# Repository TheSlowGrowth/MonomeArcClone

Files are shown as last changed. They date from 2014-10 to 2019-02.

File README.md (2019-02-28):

# Monome Arc Clone

An open source, protocol-compatible clone of the monome arc.

## Before you start

Please note: if you encounter a problem, please **do not post on the
monome forums**! Tehn will surely help you, but I don’t want my clone
to cause them trouble and work. I’m very happy that they make their
protocols open and I would like them to continue to do so in the spirit
of openness.

For assistance, please write an email to my address instead:
<mail@johannesneumann.net> I will try to help you out.

## Required tools

During assembly and setup you will need the following tools

-   AVR ISP programming device (supported by avrdude). I recommend
    [USBasp](http://www.fischl.de/usbasp/) or any of its clones.
    Alternatively you can also use STK500v2 clones or any other
    programmer that supports the ISP protocol. You get something like
    this on ebay for under 20€.
-   Soldering iron, decent(!) flux, tweezers, solder wick
-   a computer capable of flashing AVRs and FTDI EEPROMs
-   a multimeter

## Software installation

Before you start, please install all the software that’s needed to run monome devices. Please look at the instructions provided by [http://monome.org](http://monome.org/). Even though you might not have a functioning monome at this point, we will need the drivers during the setup process.

Install the drivers for your AVR ISP programmer, if you haven’t already.

### Windows

Install *WINAVR* from [this link](http://www.webring.org/l/rd?ring=avr;id=59;url=http://winavr.sourceforge.net/). This will install a AVR compiler and (more important) a tool called *avrdude* to upload the software to the ATMega88p microprocessor used in the device.

Install *AVR-Burn-O-Mat* from [this link](http://avr8-burn-o-mat.aaabbb.de/). This little tool will make it easier to upload the software to the chip as it provides a nice graphical user interface to *avrdude* installed with WINAVR.

Now we need to edit some files. Unfortunately as I am writing this (05.11.2014) it seems that some versions of *avrdude* and *AVR-Burn-O-Mat* don’t know the ATMega88p processor yet. So we teach them that it exists.

First, go to C:\\WINAVR\...\....\\bin\\avrdude.conf and open it with a text editor (I recommend geany).

Search for "ATMega88p". If it takes you to something like this:

```
#------------------------------------------------------------

# Atmega88p

#------------------------------------------------------------
```

…then you don’t have to edit anything and the file is fine. Simply go to the next step.

If nothing is found, search for this part:

```
#------------------------------------------------------------

# ATmega88

#------------------------------------------------------------
```

This is the header for the (almost) equal ATMega88. We simply copy the whole passage below this line (down to the next similar looking header) and change a few things. The whole passage you have to copy is roughly 200 lines long.

Duplicate the whole passage and change the beginning to:

```
#------------------------------------------------------------

# ATmega88p

#------------------------------------------------------------

part

id = "m88p";

desc = "ATMEGA88P";

has_debugwire = yes;

flash_instr = 0xB6, 0x01, 0x11;

eeprom_instr = 0xBD, 0xF2, 0xBD, 0xE1, 0xBB, 0xCF, 0xB4, 0x00,

0xBE, 0x01, 0xB6, 0x01, 0xBC, 0x00, 0xBB, 0xBF,

0x99, 0xF9, 0xBB, 0xAF;

stk500_devcode = 0x73;

# avr910_devcode = 0x;

signature = 0x1e 0x93 0x0f;

pagel = 0xd7;

bs2 = 0xc2;

...

... more stuff follows here ...

...
```

Now avrdude knows the microprocessor.

Now we have to teach *AVR-Burn-O-Mat* as well. Go to the installation directory (mine is: `D:\Program Files (x86)\AVR Burn-O-Mat)` and open the file `AVR8_Burn_O_Mat_Config.xml`. With a text editor (e.g. geany).

Again, search for "Atmega88p". If it can be found, all is well and you don't have to do anything here. If nothing is found, search for "Atmega88". It should take you to this line:

```
<AVR name="m88" caption="ATmega88">
   <Fuse name="UNUSED_E7" bit="7" ...

```
Copy the whole block (everything between `<AVR name="m88" ... ` and `</AVR>`) and change the first line to 
```
<AVR name="m88p" caption="ATmega88p">
```
Now *AVR-Burn-O-Mat* can program your Atmega88p processor.

Now open *AVR-Burn-O-Mat* and go to the settings page. Check if the directories are correct and enter the connection settings for your programmer.

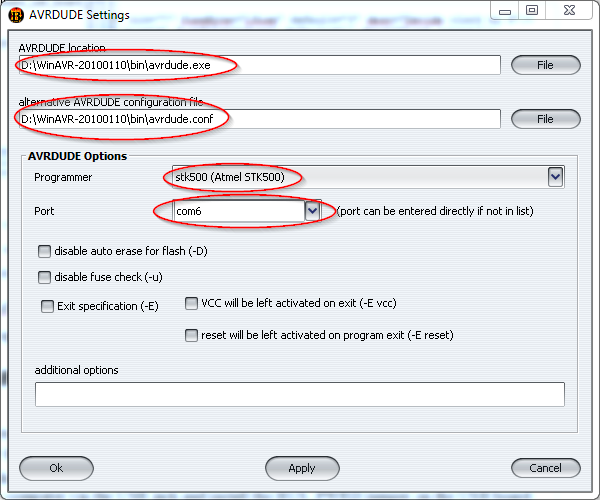
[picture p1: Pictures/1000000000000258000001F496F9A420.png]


I’m using an STK500V2 clone here, but if you click the dropdown menu, it will give you other options, such as USBasp. For most USB programmers, the Port must be set to "usb" or (if they are based on a serial COM interface) the respective COM port. You can open the device manager and plug in your programmer, then it should display the COM port in brackets behind the device name.

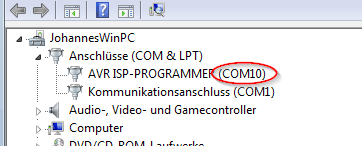
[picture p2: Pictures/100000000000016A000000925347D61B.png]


Install FT-Prog from [this website](http://www.ftdichip.com/Support/Utilities.htm). We will need it to configure the FTDI USB chip on the board.

### Linux

On Linux, install avrdude using your system’s package manager.

Compile libftdi with the confuse library already present, and make sure you can run the ftdi_eeprom command it comes with. This is currently untested on linux, please refer to [this guide](https://waterpigs.co.uk/articles/ftdi-configure-mac-linux/) for pointers on how to do it.

### Mac OS X

Install avrdude, and avr-gcc if you want to compile your own hex files. You can do this either manually, or via [CrossPack](https://obdev.at/products/crosspack/download.html).

In order to be able to flash the FTDI chip’s EEPROM, you’ll need to install libftdi with the confuse library already installed. This is possible either manually, or using homebrew with a change to the libftdi formula detailed [here](https://waterpigs.co.uk/articles/ftdi-configure-mac-linux/).

Some old versions of CrossPack will be missing the avrdude reference files for the ATMega88p. You can test this by running `avrdude -c stk500v2 -p m88p`. If you get `avrdude: AVR Part "88p" not found.` then follow the instructions in the Windows section above, duplicating the ATMega88 definition for the 88p. Look for an avrdude.conf file to make these changes in, e.g. `/usr/local/CrossPack-AVR-20100115/etc/avrdude.conf`

## USB Board Assembly

I won’t give step-by-step instructions for soldering. If you are not familiar with soldering and electronics in general, please do an easier project first. It can become very frustrating otherwise.

Once you’re done assembling the USB board, go to the device manager (Windows) or USB Prober (Mac OS). Connect the USB board to your computer via the USB jack and install the BUS\_PWRD jumper on the USB board. You should see the device manager refresh and a new COM port device will appear.

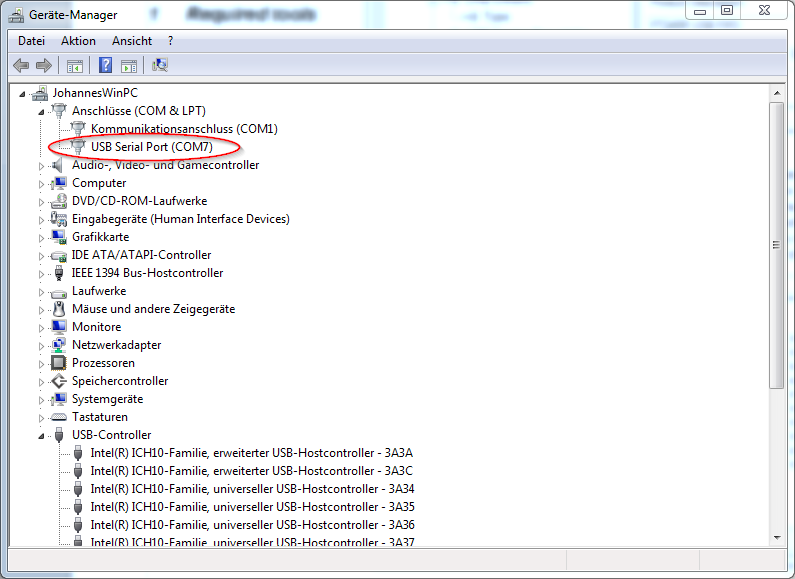
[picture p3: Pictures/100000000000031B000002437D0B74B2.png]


If it does not appear, please disconnect it immediately and check your soldering!

Now we have to check the voltage of the on-board regulator. Connect a multimeter to the pins highlighted in the following picture:

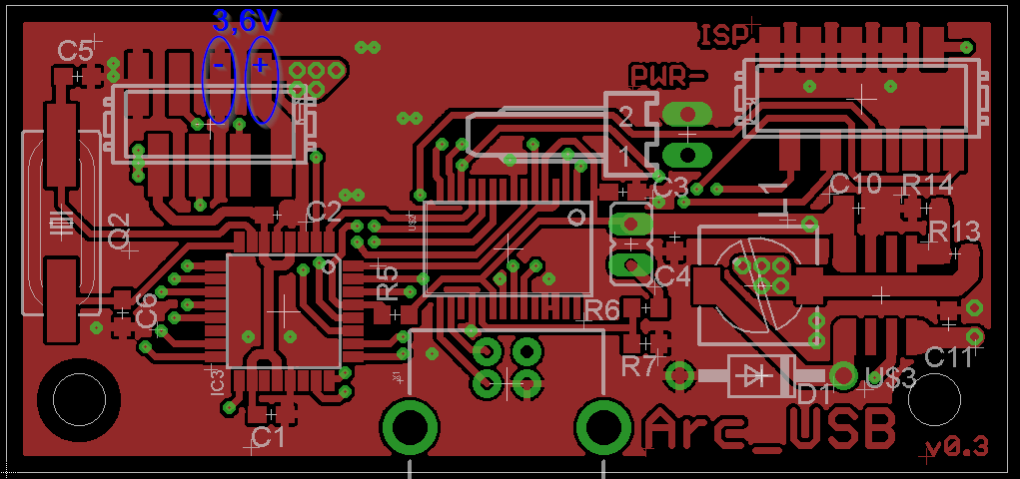
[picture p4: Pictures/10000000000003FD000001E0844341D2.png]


Your meter should read 3,6V (or thereabouts). Fine, it looks like everything is okay.

Lets go on and flash the firmware to the chip. Connect your programmer to the 10-pin connector on the USB board. This connector is not the one commonly used for AVR devices, but it uses the same pinout and attaches to the same type of cables. You can simply use your programmers 10-pin cable and crimp micromatch connector to it. This should now be plugged into the USB board. Check the orientation. A good help can be the four ground-pins, which are connected to each other. On both the USB board and the programmer. Pin 1 of the cable is on the opposite side. In the image above, it is the pin on the bottom right of the connector, next to the "R14" label.

Also be sure, that the USB board is plugged into your computer as well and the BUS\_PWRD jumper is installed, so the processor receives power.

### Windows (AVR-Burn-O-Mat + FT_PROG)

Open *AVR-Burn-O-Mat *and connect your programmer to your PC.

First, we need to change the fuse-bits in the processor, to use the external 20MHz crystal as a clock source. Select Atmega88p from the "AVR type" menu. Then click on "Fuses"

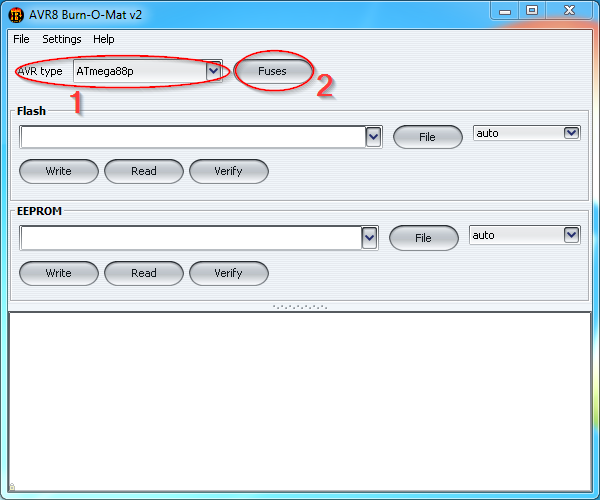
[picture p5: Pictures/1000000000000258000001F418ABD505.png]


In the new window, click "read fuses".

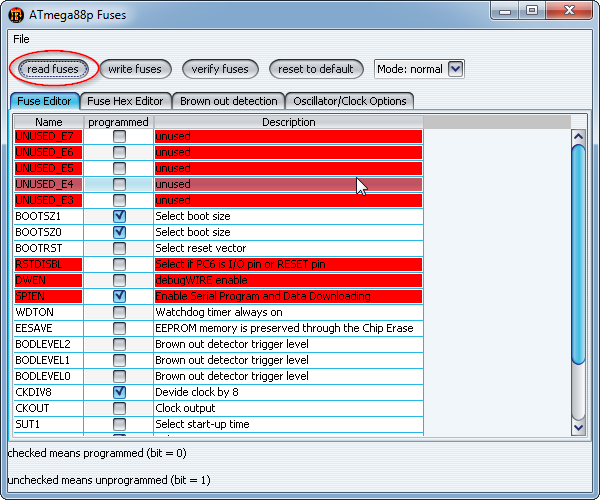
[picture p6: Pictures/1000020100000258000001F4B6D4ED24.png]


You should see some commands run in the bottom of the main window and eventually a message will pop up, saying: "fuses successfully read". If not: Check the commands in the main window. They can give you a hint to where the problem is. Usually the programmer settings are wrong (wrong COM port\...) or the USB board is not connected properly. Some programmers offer a "low speed" programming mode, this should be used, as the processor is currently still running at its internal low clock speed.

If verything is fine, we can edit the fuse-bits to use the external crystal. Click on the "Oscillator/Clock Options" tab, then un-tick "divide system clock by 8" and select the "Full swing crystal oscillator" tab.

Double check everything! You might screw your chip up! Never attempt to write the fuses, if you were not able to correctly read them before. You might end up with a chip that has its programming interface disabled and can’t be rescued even with professional equipment.

Okay, once you are sure, everything is correct and matches the image below, you can click "write fuses" and again, some commands should run in the main window and a message should say: "Fuses successfully written". Then click "read fuses" again. If they can be read successfully, you have done everything right.

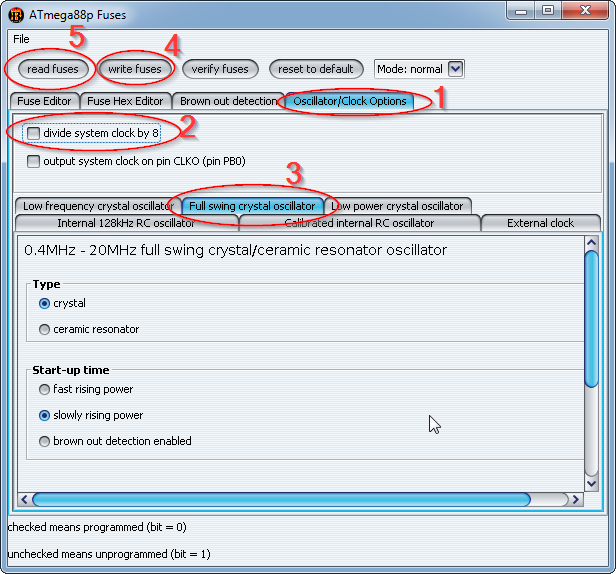
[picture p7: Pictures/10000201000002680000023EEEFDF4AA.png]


Now we can flash the firmware. Close the fuses window and select the firmware file in the main window. I recommend to use the pre-compiled one in the repository. I want to build an arc 4 here, so I chose the matching firmware. Be sure to use the right file. Using another file will probably make the processor "think" its connected to some hardware which is not there. This can create short circuits and might destroy the chip. So please double check here!

Click "write" and the commands in the bottom of the window should start executing again. Eventually it will say "Flash sucessfully written."

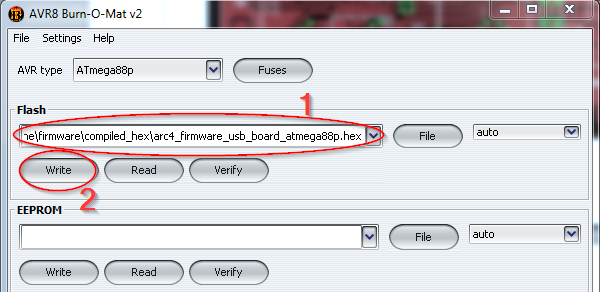
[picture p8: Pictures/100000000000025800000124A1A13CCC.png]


Nice! Now you can unplug the programmer.

Now we have to configure the USB-chip on the board to be recognized by serialosc so you can use your clone just like a real monome arc.

Start FT\_PROG and connect the USB board to your computer via its USB connector. In the FT\_PROG window, click the search icon until it displays your device.

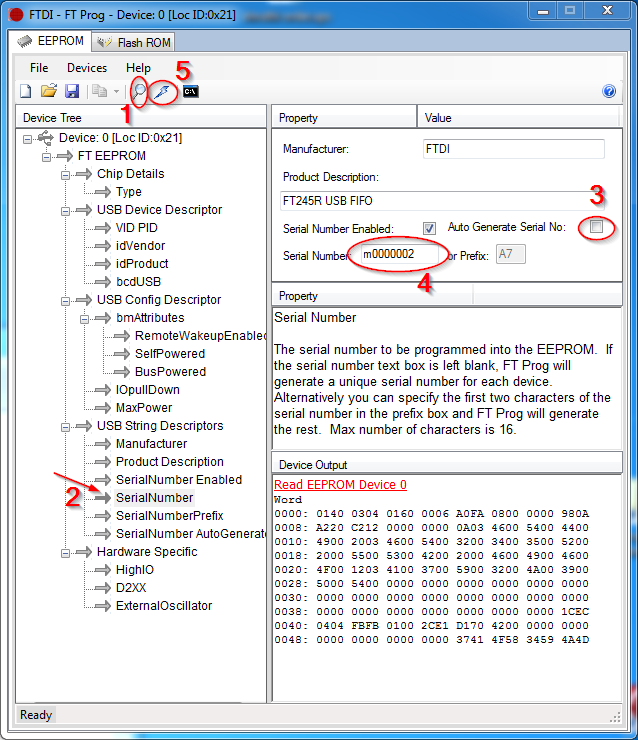
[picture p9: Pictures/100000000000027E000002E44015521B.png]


Eventually after a few retries you get this. Go to the "SerialNumber" tab and untick "Auto Generate Serial No:". Now you can edit the "serial number" field. Enter a serial number like in the image above. It should start with an "m" and the numbers after that are irrelevant, but I found that they should be 7 digits long. They represent the "unique number" of your device. If you have other monomes, be sure that you use a different serial number that the one of your other devices. Also change the manufacturer to "monome", this is important for compatibility with monome eurorack modules and the Aleph. Once you’re done, click the flash symbol and program the new settings to the chip.

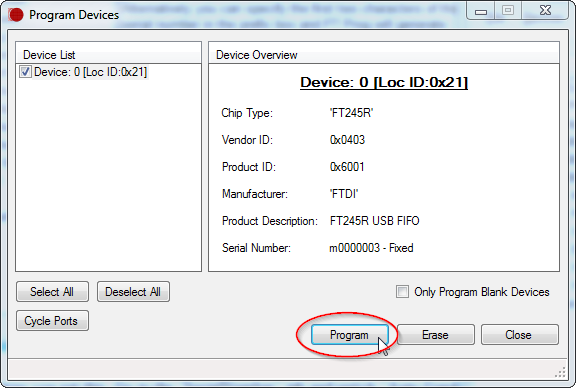
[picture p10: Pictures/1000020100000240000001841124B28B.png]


### Linux/Mac OS (avrdude + libftdi ftdi_eeprom)

Connect your AVR programmer to your computer, and the USB board to the programmer. In each of the following commands, replace `YOUR_PROGRAMMER_ID` with the relevant ID (e.g. stk500v2) and `YOUR_PROGRAMMER_PORT` with the relevant port (e.g. `/dev/cu.usbmodem00177932`.

First, set the fuses, based on [this fuse calculation](http://eleccelerator.com/fusecalc/fusecalc.php?chip=atmega88p&LOW=D6&HIGH=DF&EXTENDED=F9&LOCKBIT=FF):

`avrdude -V -p m88p -c YOUR_PROGRAMMER_ID -P YOUR_PROGRAMMER_PORT -B 10 -e -u -U lfuse:w:0xD6:m -U hfuse:w:0xDF:m -U efuse:w:0xF9:m -U lock:w:0xFF:m`

Then, flash the USB board firmware. Swap `arc4_` for `arc2_` in the unlikely event you’re building a two-ring arc:

`avrdude -V -p m88p -c YOUR_PROGRAMMER_ID -P YOUR_PROGRAMMER_PORT -B 2 -U flash:w:./firmware/compiled_hex/arc4_firmware_usb_board_atmega88p.hex:i -U lock:w:0xFF:m`

To flash the FTDI EEPROM, edit `firmware/monome-arc-clone-ftdi-eeprom.conf` to have your desired serial number (which must be m followed by seven digits), then run the following command with your FTDI driver disabled:

`ftdi_eeprom --flash-eeprom firmware/monome-arc-clone-ftdi-eeprom.conf`

Don’t forget to re-enable your FTDI driver afterwards! Refer to this [libftdi guide](https://waterpigs.co.uk/articles/ftdi-configure-mac-linux/) for more information.

### Testing

Now you can open a monome app with your USB board connected, and you should see your clone appear in the device list. If it does not appear, check your serialosc settings.

## Pot board and ring board assembly

Assemble the ring boards and the pot boards. Start with one pair of them to find errors early.

At full brightness, each LED is supplied with a 3.3V square wave with 25% duty cycle, current limited to around 2.6mA (with a 9.1kohm current set resistor). Not all LEDs perform well at such low currents. Testing found the IN-S63AT5UW to be an excellent trade-off between price and performance. Prices in the comparison are from late 2018.

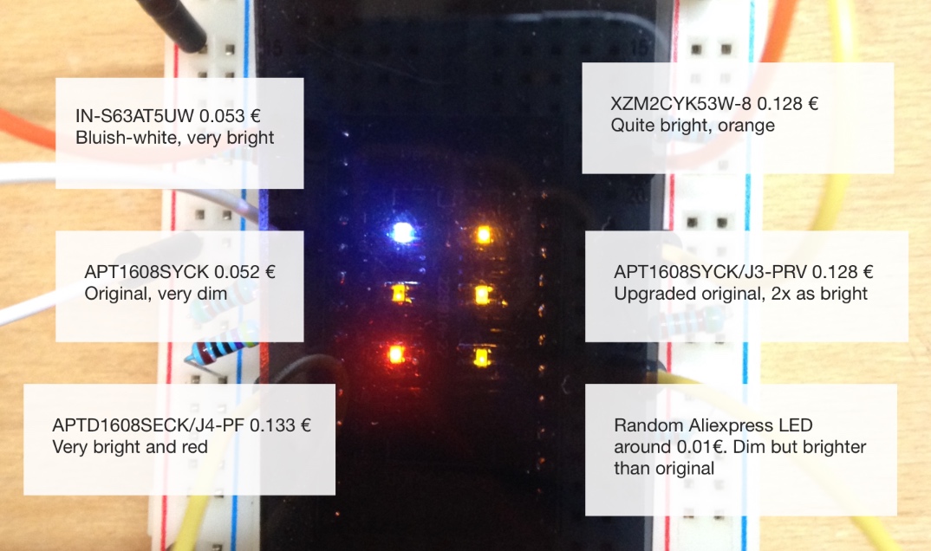
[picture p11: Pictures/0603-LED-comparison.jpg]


When soldering the surface mounted headers which connect each ring board to the encoder board, solder only one connector first, insert the other connector onto that, then temporarily screw the boards together and make a couple of solder joints to fix the other connector in exactly the right mating position. If soldered without checking the location, you risk the boards being misaligned.

Use the 8pin micromatch connectors and ribbon cables to connect the pot board to the USB board via their micromatch connectors (Not the one marked with ISP, the smaller one.) Connect the USB board to your computer and check the BUS\_PWRD jumper. The USB board should now receive power, and supply the pot board via the ribbon cable that connects the two.

Attach your AVR programmer to the board, then set the fuses and flash the firmware as with the USB Board, but using `firmware_pot_board_atmega88p.hex` rather than the USB board hex file.

Once the pot boards processor is programmed with the right fuses and firmware, you should disconnect the usb cable and set the address selection switch to off/off. This equals to address 0, which is used for the first LED ring in the monome arc clone.

Now attach the led ring.

Connect the USB board to the computer again and the led ring should light up for a short time (part of the startup animation). Open the [monome arc test app](http://docs.monome.org/lib/exe/fetch.php?media=app:monome_test_110.zip) and check everything.

Then assemble the other boards and connect them to the ribbon cable. Flash them the same way and check them with the test app. Be sure to use the right addresses:

```
  ------------- ---------- ----------
  Ring number   Switch 2   Switch 1
  0             Off        Off
  1             Off        On
  2             On         Off
  3             On         On
  ------------- ---------- ----------
```

Double check that all the boards function correctly before final assembly. Make sure that all LEDs light, that the encoders send turn and button press messages, and that the boards are in the right order.

If you don’t have Max MSP and don’t want to install the very large free Max player, you can use the small Puredata arc test patch in `firmware/arc-scratchpad.pd` to test and debug your arc. It should run in any version of Puredata, and requires no externals.

## Physical Case Construction and Assembly

Assuming you’re working with a milled panel based on `case/Alu Faceplate.pdf` and laser cut acrylic parts based on the Glas-Ring and Light_Shaper drawings, assembly is quite straightforward. The fit of the laser cut parts is tight, and often the outer diameter is slightly larger on one edge than the other, so look carefully at the edge angles of both parts and experiment with their orientation to find the best results. You can see the angles here:

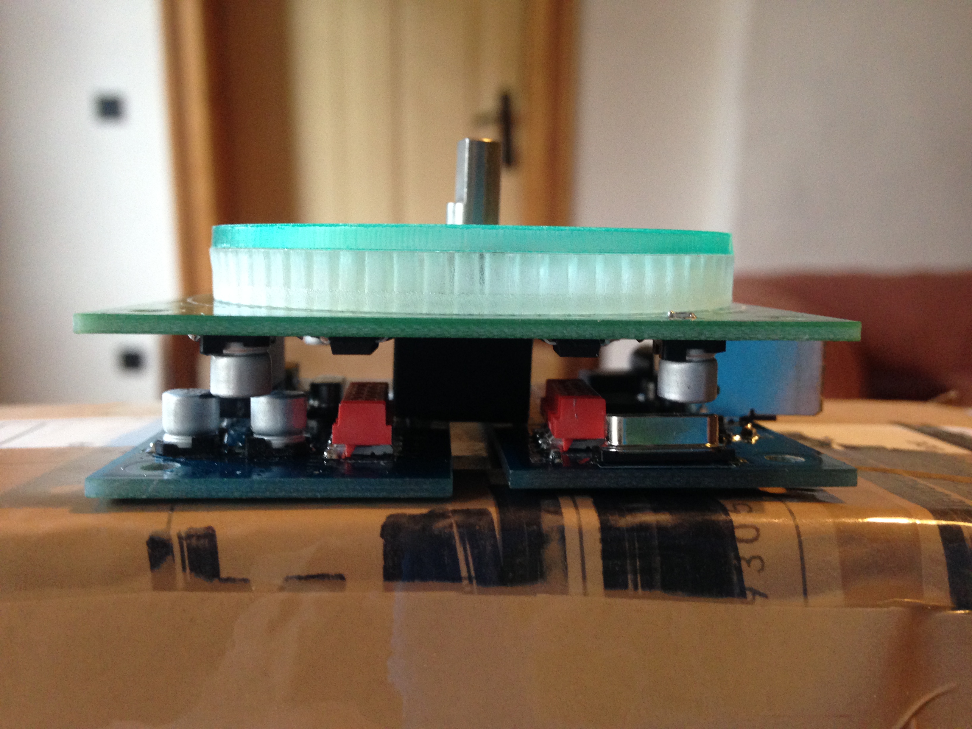
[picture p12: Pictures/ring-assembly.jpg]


Depending on the quality of your laser cutter, you may have to manually remove some leftover parts from the light shaper with a small sharp knife.

For a more diffused light from the LEDs, either cut the rings from frosted acyrlic, lightly sand the underside of the rings with 400 grit sandpaper, or perhaps put a ring of very thin paper between the ring and light shaper.

The blind threaded holes in the top panel are not deep enough for normal male-female M3 hex spacers, so insert 12mm setscrews (preferably fastened with thread lock e.g. loctite) and then screw 4mm female-female hex spacers over them before attaching the ring board.

The simplest case solution is to cut a 4mm acrylic backplate from `case/Acrylic Glass Back Panel 266 x 74.svg`, then assemble the boards and plates as shown (note that the given acrylic back plate has one set of mounting holes in a different location to shown here. Either cut the backplate with holes in the outside corners, or alter the assembly to suit):

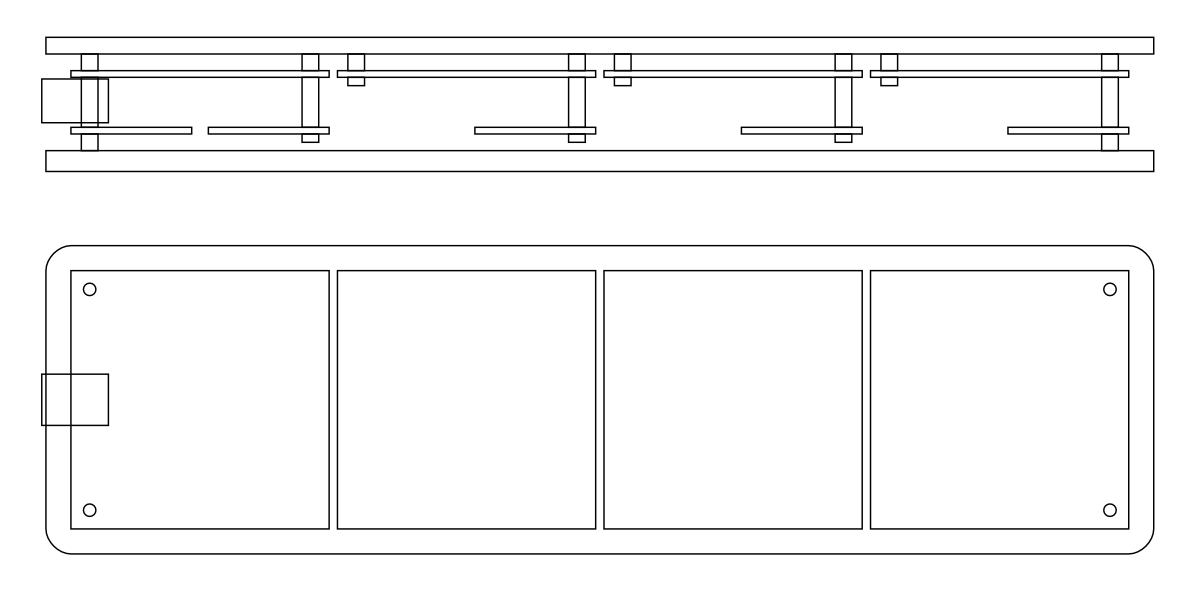
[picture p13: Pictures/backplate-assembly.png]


You’ll need the following hardware:

* 16 x 12mm M3 Set Screw
* 16 x 4mm M3 FF hex spacer
* 10 x 12mm M3 FF hex spacer
* 4 x 4mm M3 MF hex spacer
* 6 x M3 Nut
* 6 x 6mm M3 Screw
* 4 x 8mm M3 Screw

If you want to build a more comprehensive case, refer to the layout in `case/Monome Arc Clone Walnut Case.ezdraw` and `case/Monome Arc Clone Walnut Case Plans 500 x 360.svg` for dimensions to design a case around. Make sure the bounding box in the SVG is scaled to 500mm by 360mm in your CAD application, and then everything else should be the correct size. Parts for the CNC-routed wooden case and knobs shown below are given as an example.

Congratulations on assembling your arc!

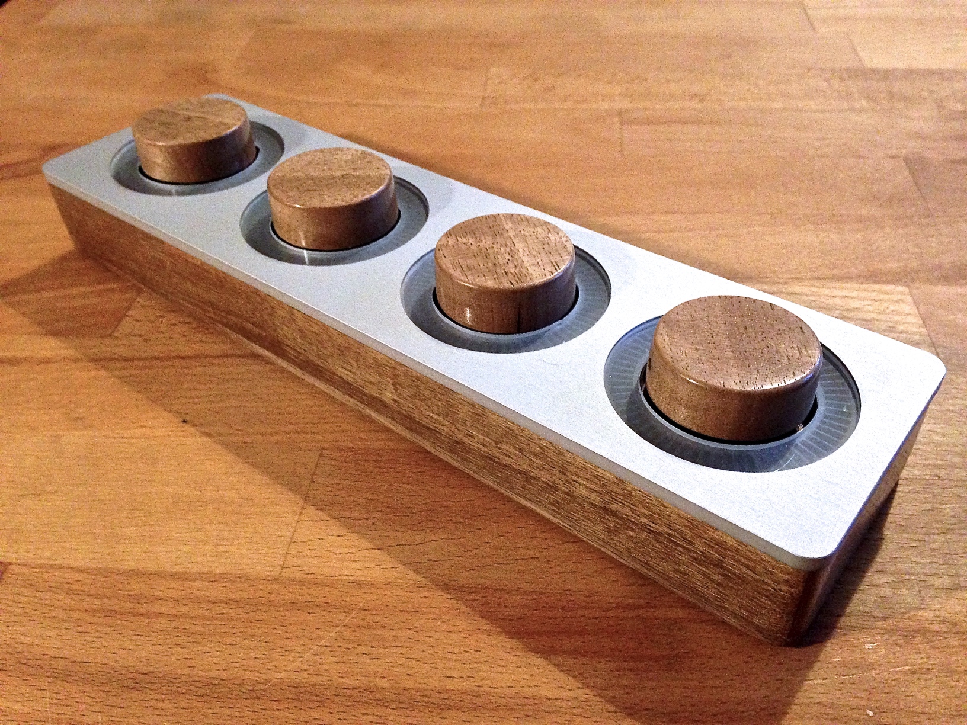
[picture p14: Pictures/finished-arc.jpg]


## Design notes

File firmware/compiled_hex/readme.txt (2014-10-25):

For an arc2:
- flash USB board with "arc2_firmware_usb_board_atmega88p.hex"
- flash all pot boards with "firmware_pot_board_atmega88p.hex"

For an arc4:
- flash USB board with "arc4_firmware_usb_board_atmega88p.hex"
- flash all pot boards with "firmware_pot_board_atmega88p.hex"

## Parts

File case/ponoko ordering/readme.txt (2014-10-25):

use these files to order the light shaper and the "glass" ring from ponoko laser cutting service.

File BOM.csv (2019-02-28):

Part |  |  | Quantity needed for
Name | Mouser Nr. | Reichelt Nr. | 1x ring board | 1x encoder board | 1x usb board | complete Arc 2 | complete Arc 4
ATMega88PA-AU | 556-ATMEGA88PA-AU |  |  | 1 | 1 | 3 | 5
L5970D DC/DC regulator | 511-L5970D |  |  |  | 1 | 1 | 1
FT245RL | 895-FT245RL |  |  |  | 1 | 1 | 1
TLC5940 | 595-TLC5940PWP |  | 1 |  |  | 2 | 4
74HC595 | 771-74HC595D-T |  | 1 |  |  | 2 | 4
MOSFET IRLML5203 | 942-IRLML5203TRPBF |  |  | 1 |  | 2 | 4
MOSFET BSP171P | 726-BSP171PH6327XTSA |  | 4 |  |  | 8 | 16
LED (small!) | IN-S63AT5UW recommended, see docs |  | 64 |  |  | 128 | 256
diode MBRS240LT3G | 863-MBRS240LT3G |  |  |  | 1 | 1 | 1
crystal 20MHz | 520-200-18-5PXEN |  |  | 1 | 1 | 3 | 5
ceramic cap 22pF | 77-VJ0603A220JXACBC |  |  | 2 | 2 | 6 | 10
ceramic cap 220pF | 581-06033A221FAT2A |  |  |  | 1 | 1 | 1
ceramic cap 10nF | 77-VJ0603Y103KXAAC |  |  | 3 |  | 6 | 12
ceramic cap 22nF | 77-VJ0603V223ZXXPBC |  |  |  | 1 | 1 | 1
ceramic cap 100nF | 77-VJ0603Y104JXQCBC |  | 7 | 5 | 4 | 28 | 52
ceramic cap 10uF | 81-GRM188R61A106ME9D |  |  |  | 1 | 1 | 1
electrolytic cap 10uF | 140-VE100M1HTR0505 |  | 4 | 2 |  | 12 | 24
resistor 330 | 71-CRCW0603-330-E3 |  |  | 3 |  | 6 | 12
resistor 1k | 71-CRCW0603-1.0K-E3 |  |  | 1 |  | 2 | 4
resistor 3k3 | 71-CRCW06033K32FKEB |  |  |  | 3 | 3 | 3
resistor 4k7 | 594-MCT06030C4701FP5 |  | 4 | 3 | 2 | 16 | 30
resistor 5k6 | 594-MCT06030C5601FP5 |  |  |  | 1 | 1 | 1
resistor 10k | 71-CRCW0603-10K-E3 |  | 1 | 2 | 3 | 9 | 15
current-set resistor | 9.1k 1206 is a good starting point |  | 1 |  |  | 2 | 4
inductor 15uH | 704-DRA73-150-R | L-PIS2816 15µ |  |  | 1 | 1 | 1
adress selection switch 2 pole | 774-2192MST |  |  | 1 |  | 2 | 4
USB B connector | 649-61729-1011BLF |  |  |  | 1 | 1 | 1
2pin molex connector, angled (optional) |  |  |  |  | 1 | 1 | 1
2x1 pinheader male |  |  |  |  | 1 | 1 | 1
2x5 pinheader male, SMD |  |  | 1 |  |  | 2 | 4
2x5 pinheader female, SMD |  |  |  | 1 |  | 2 | 4
jumper bridge |  |  |  |  | 1 | 1 | 1
micromatch 2x4 female | 571-338069-8 |  |  | 1 | 1 | 3 | 5
micromatch 2x4 male | 571-215083-8 |  |  | 1 | 1 | 3 | 5
micromatch 2x5 female | 571-8-188275-0 |  |  | 1 | 1 | 3 | 5
micromatch 2x5 male (for programming) | 571-8-215083-0 |  |  | 1 | 1 | 1 | 1
Bourns EM14 encoder | 652-EM14ROD-M20L064S |  |  | 1 |  | 2 | 4
8pole /10pole cable for micromatch |  |  |  | 3 |  | 6 | 12
All ceramic capacitors and most resistors in 0603 package

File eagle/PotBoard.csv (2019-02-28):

Qty | Value | Device | Package | Parts | Description | MF | MPN | OC_FARNELL | OC_NEWARK
1 |  | MICROMATCH-10-SMD | MICROMATCH-10-SMD | ISP
1 |  | PINHD-2X5_2.54-SMD | 2X05SMD | JP4 | PIN HEADER
5 | 100n | C-EUC0603 | C0603 | C13, C14, C15, C16, C17 | CAPACITOR, European symbol
2 | 10k | R-EU_R0603 | R0603 | R1, R5 | RESISTOR, European symbol
3 | 10n | C-EUC0603 | C0603 | C7, C8, C9 | CAPACITOR, European symbol
2 | 10u | CPOL-EU153CLV-0505 | 153CLV-0505 | C3, C4 | POLARIZED CAPACITOR, European symbol
1 | 1k | R-EU_R0603 | R0603 | R15 | RESISTOR, European symbol
1 | 20MHz | CRYSTALSM49 | SM49 | Q1 | CRYSTAL
1 | 219-02 | 219-02 | CTS-219-02 | ADRESS | Surface Mount DIP Switch Series 219 SMT |  |  | unknown | unknown
2 | 22p | C-EUC0603 | C0603 | C1, C2 | CAPACITOR, European symbol
3 | 330 | R-EU_R0603 | R0603 | R2, R3, R4 | RESISTOR, European symbol
3 | 4k7 | R-EU_R0603 | R0603 | R9, R10, R11 | RESISTOR, European symbol
1 | BOURNS_EM14 | BOURNS_EM14 | BOURNS_EM14_AXIAL | U$1 | Bourns EM14 optical encoder
1 | IRLML5203 | IRLML5203 | MICRO3 | Q3 | HEXFET P-Channel Power MOSFET
1 | MEGA8-AI | MEGA8-AI | TQFP32-08 | IC1 | MICROCONTROLLER
1 | MICROMATCH-8SMD | MICROMATCH-8SMD | MICROMATCH-8-SMD | X1 | MicroMaTch 8 7-215464-8 / 0-215464-8

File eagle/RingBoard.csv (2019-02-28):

Qty | Value | Device | Package | Parts | Description
64 |  | LEDCHIP-LED0805 | CHIP-LED0805 | LED1, LED2, LED3, LED4, LED5, LED6, LED7, LED8, LED9, LED10, LED11, LED12, LED13, LED14, LED15, LED16, LED17, LED18, LED19, LED20, LED21, LED22, LED23, LED24, LED25, LED26, LED27, LED28, LED29, LED30, LED31, LED32, LED33, LED34, LED35, LED36, LED37, LED38, LED39, LED40, LED41, LED42, LED43, LED44, LED45, LED46, LED47, LED48, LED49, LED50, LED51, LED52, LED53, LED54, LED55, LED56, LED57, LED58, LED59, LED60, LED61, LED62, LED63, LED64 | LED
1 |  | PINHD-2X5_2.54-SMD | 2X05SMD | JP1 | PIN HEADER
7 | 100n | C-EUC0603 | C0603 | C1, C2, C3, C5, C6, C7, C8 | CAPACITOR, European symbol
1 | 10k | R-EU_R0603 | R0603 | R2 | RESISTOR, European symbol
4 | 10u | CPOL-EU153CLV-0605 | 153CLV-0605 | C9, C10, C11, C12 | POLARIZED CAPACITOR, European symbol
4 | 4k7 | R-EU_R0603 | R0603 | R4, R5, R6, R7 | RESISTOR, European symbol
1 | 74HC595D | 74HC595D | SO16 | IC2 | 8-bit SHIFT REGISTER, output latch
4 | BSP171P | BSP170P | SOT223 | Q1, Q2, Q3, Q4 | SIPMOS(R) Small-Signal-Transistor P-Channel, Enhancement mode
1 | I_SET_RESISTOR | R-EU_M1406 | M1406 | R3 | RESISTOR, European symbol
1 | TLC5940-TSSOP | TLC5940-TSSOP | HTSSOP-28 | U$2

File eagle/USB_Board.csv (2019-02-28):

Qty | Value | Device | Package | Parts | Description
1 |  | JP1Q | JP1 | BUS_PWRD | JUMPER
1 |  | MICROMATCH-10-SMD | MICROMATCH-10-SMD | ISP1
4 | 100n | C-EUC0603 | C0603 | C1, C2, C3, C4 | CAPACITOR, European symbol
3 | 10k | R-EU_R0603 | R0603 | R5, R7, R8 | RESISTOR, European symbol
1 | 10uF | C-EUC0805 | C0805 | C10 | CAPACITOR, European symbol
1 | 15uH | L-EUPIS2816 | PIS2816 | L1 | INDUCTOR, European symbol
1 | 20MHz | CRYSTALSM49 | SM49 | Q2 | CRYSTAL
1 | 22-05-7028-02 | 22-05-7028-02 | 7395-02 | POWER | CONNECTOR
1 | 220p | C-EUC0603 | C0603 | C11 | CAPACITOR, European symbol
1 | 22n | C-EUC0603 | C0603 | C12 | CAPACITOR, European symbol
2 | 22p | C-EUC0603 | C0603 | C5, C6 | CAPACITOR, European symbol
3 | 3k3 | R-EU_R0603 | R0603 | R1, R2, R14 | RESISTOR, European symbol
2 | 4k7 | R-EU_R0603 | R0603 | R6, R12 | RESISTOR, European symbol
1 | 5k6 | R-EU_R0603 | R0603 | R13 | RESISTOR, European symbol
1 | FT245RL | FT245RL | SSOP28DB | U$2 | USB FIFO Controller
1 | L5970AD | L5970AD | SO8 | U$3
1 | MBRS240LT3G | 1N4004 | DO41-10 | D1 | DIODE
1 | MEGA8-AI | MEGA8-AI | TQFP32-08 | IC3 | MICROCONTROLLER
1 | MICROMATCH-8SMD | MICROMATCH-8SMD | MICROMATCH-8-SMD | CONN | MicroMaTch 8 7-215464-8 / 0-215464-8
1 | USBPTH | USBPTH | USB-B-PTH | X1 | USB Connectors

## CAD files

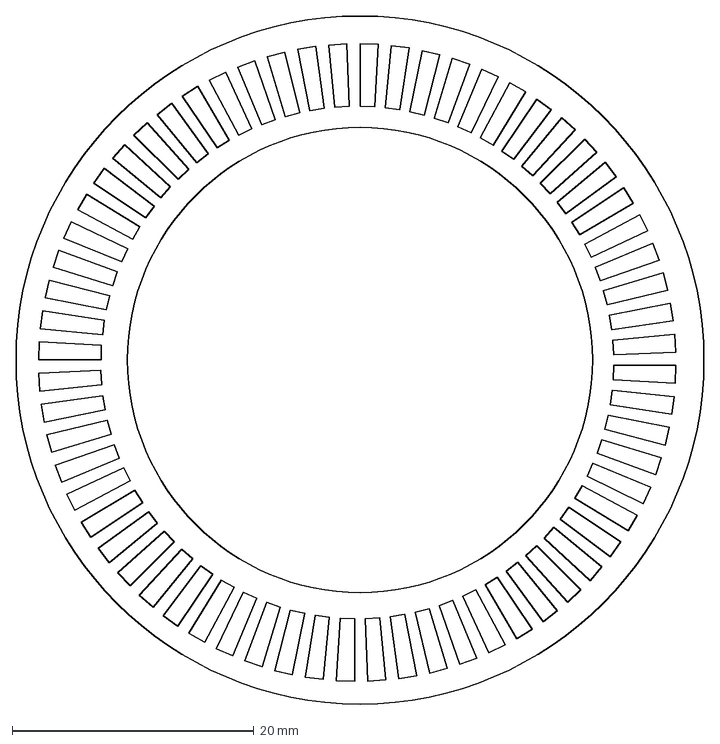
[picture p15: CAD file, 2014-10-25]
case/Plastik-Ring.DXF
56.9 x 56.9 mm

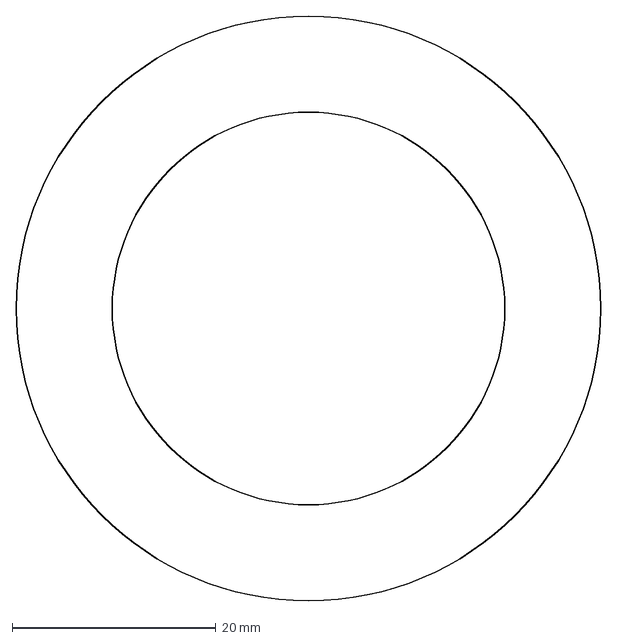
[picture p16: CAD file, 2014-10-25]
case/Glas-Ring.DXF
57.3 x 57.3 mm

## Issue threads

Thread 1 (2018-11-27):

Arc has no type/“friendly name” in serialosc device list

barnabywalters, 2018-11-27:
When I plug a monome grid 128 into my computer and request a device list from serialosc with `/serialosc/list`, it returns a list of devices, each with three fields: serial number, “type” and port. For my grid, these values are: `m0000033`, `monome 128` and whatever port serialosc has assigned to the device.

When I plug in my arc clone and list, I get the serial number I programmed the FTDI chip with and a port, but the “type” field is an empty string.

This string is pretty useful for people choosing between multiple devices, and it would be nice to have it look the same as whatever shows up when listing an arc2/4 from monome. I had a look through the source of both the arc clone firmware and serialosc to try to figure out what the suitable text would be and how to add this, but couldn’t figure it out. Within serialosc, this field seems to be referred to as “friendly_name”, but I can’t figure out exactly where it comes from.

TheSlowGrowth, 2018-11-27:
I took a look at the code. It seems the friendly_name is assigned with the function `monome_get_friendly_name()` which is defined in libmonome. Take a look at `mext.c`, line 454, this is where it is assigned during the device lookup. Apparently, the friendly name is whatever the device answers to the `Query_ID` command. In the clone, I had no clue what the ID may be for, so right now, I simply answer with a bunch of zeros - which is an empty string.

I added a quick fix on the `friendly_name_fix` branch: 91b746a can you try that out? It should report `arc2` or `arc4` as the friendly_name. I don't have time to check it myself right now, I hope this helps anyway.

TheSlowGrowth, 2018-11-29:
fixed with 65f6bdfd8ddd41d7a69304fbd2a3c681454ebe6e

Closed 2018-11-29.

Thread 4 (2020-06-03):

Light shaper proportions

vafu, 2020-06-03:
Hello, i have a question regarding positioning of light shaper windows. It’s unclear for me how are they positioned on the ring. Attaching an image.
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
Seems that these dimentions are not 1:1

TheSlowGrowth, 2021-04-06:
Sorry, I somehow didn't see this before...

The dimensions are 5:1, as stated in the drawing.
x/y are not critically important. If you machine this yourself you can pretty much set this "by eye" to any proportion that looks good. I designed it so that the LEDs are in the center of the cutouts.

The inner and outer diameter are important, though.

Closed 2021-04-06.

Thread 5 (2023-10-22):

PCB silkscreen references the components with "C14" "R2"... but the BOM does not references these

mistymountainblowtorch, 2023-10-22:
Is there a BOM that references the silkscreen relationship to chip (resistor/cap...) values?   Apologies if I missed it.

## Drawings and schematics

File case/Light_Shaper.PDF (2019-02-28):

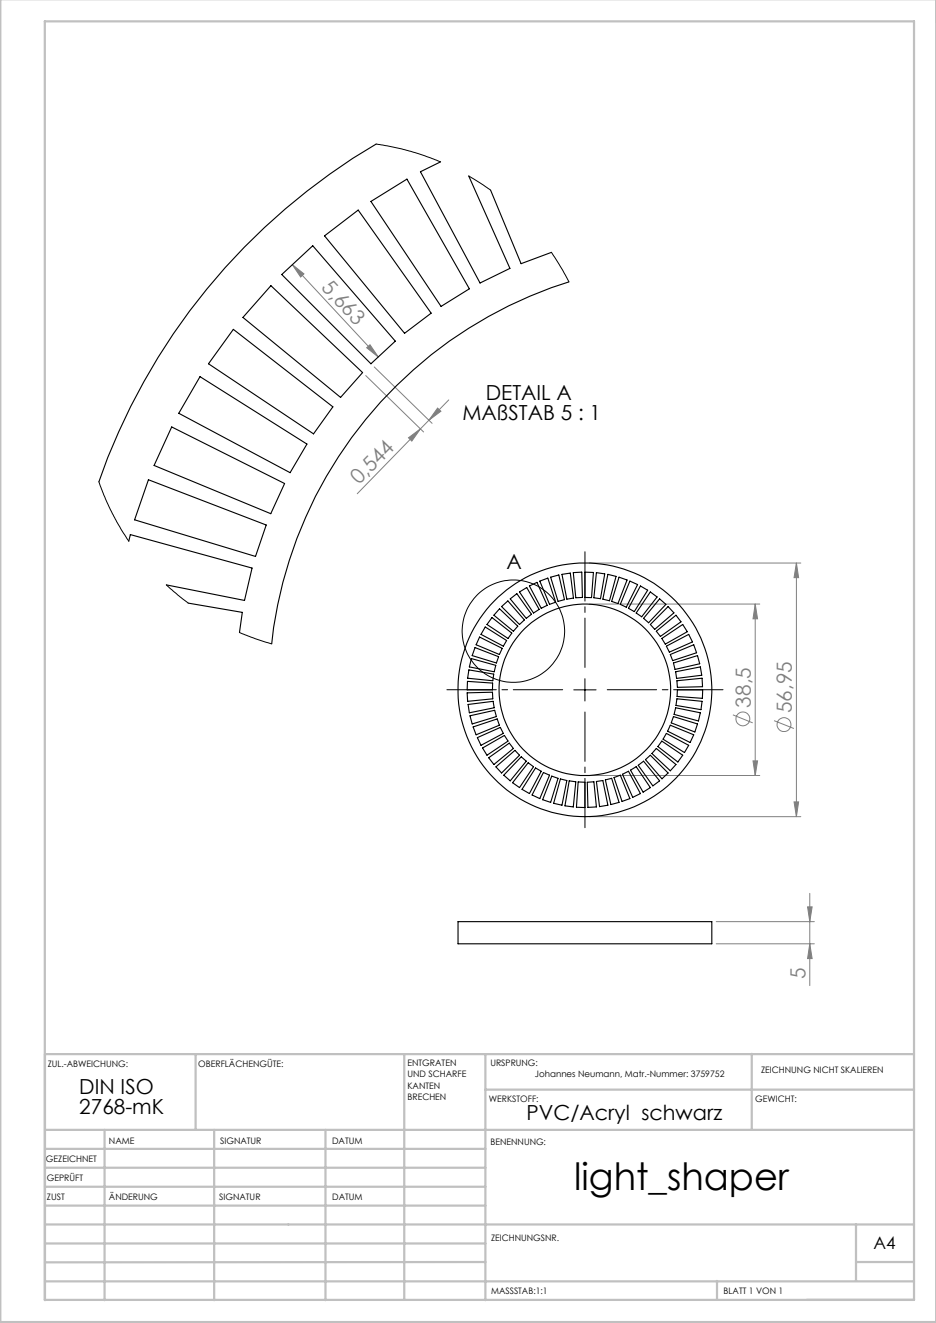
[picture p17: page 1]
DETAIL A MAßSTAB 5 : 1; MASSSTAB:1:1; BLATT 1 VON 1

ZUL.-ABWEICHUNG: DIN ISO 2768-mK | OBERFLÄCHENGÜTE: | ENTGRATEN UND SCHARFE KANTEN BRECHEN | URSPRUNG: Johannes Neumann, Matr.-Nummer: 3759752 | ZEICHNUNG NICHT SKALIEREN
NAME | SIGNATUR | DATUM | | BENENNUNG: light_shaper

WERKSTOFF: PVC/Acryl schwarz | GEWICHT:

GEZEICHNET
GEPRÜFT
ZUST | ÄNDERUNG | SIGNATUR | DATUM

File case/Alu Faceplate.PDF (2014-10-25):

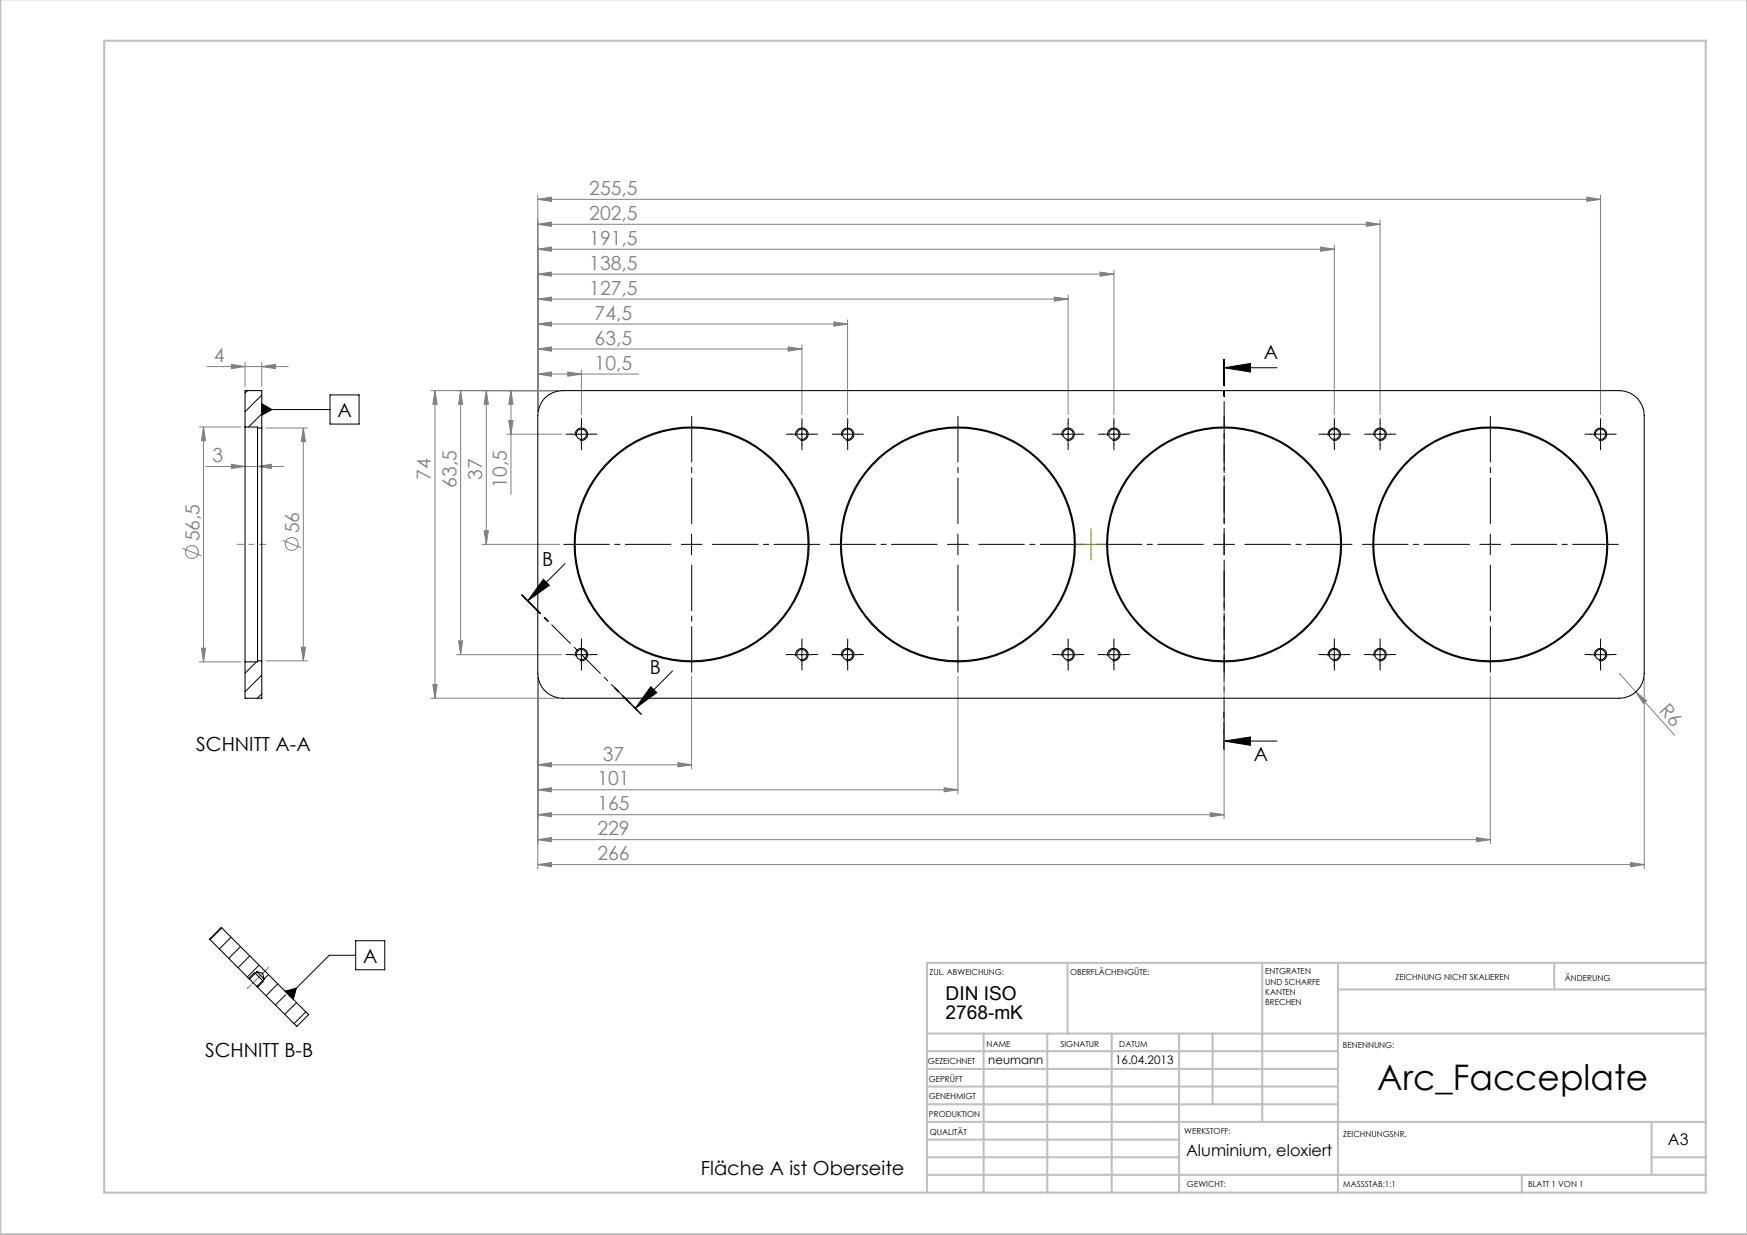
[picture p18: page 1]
SCHNITT A-A; SCHNITT B-B; MASSSTAB:1:1; BLATT 1 VON 1; ZEICHNUNG NICHT SKALIEREN; ÄNDERUNG; UND SCHARFE; ZUL. ABWEICHUNG:; OBERFLÄCHENGÜTE:; DIN ISO

NAME | SIGNATUR | DATUM | | | | BENENNUNG: Arc_Facceplate

GEZEICHNET | neumann | | 16.04.2013

GEPRÜFT
GENEHMIGT
PRODUKTION
QUALITÄT | | | | WERKSTOFF: Aluminium, eloxiert | ZEICHNUNGSNR. | A3

Fläche A ist Oberseite

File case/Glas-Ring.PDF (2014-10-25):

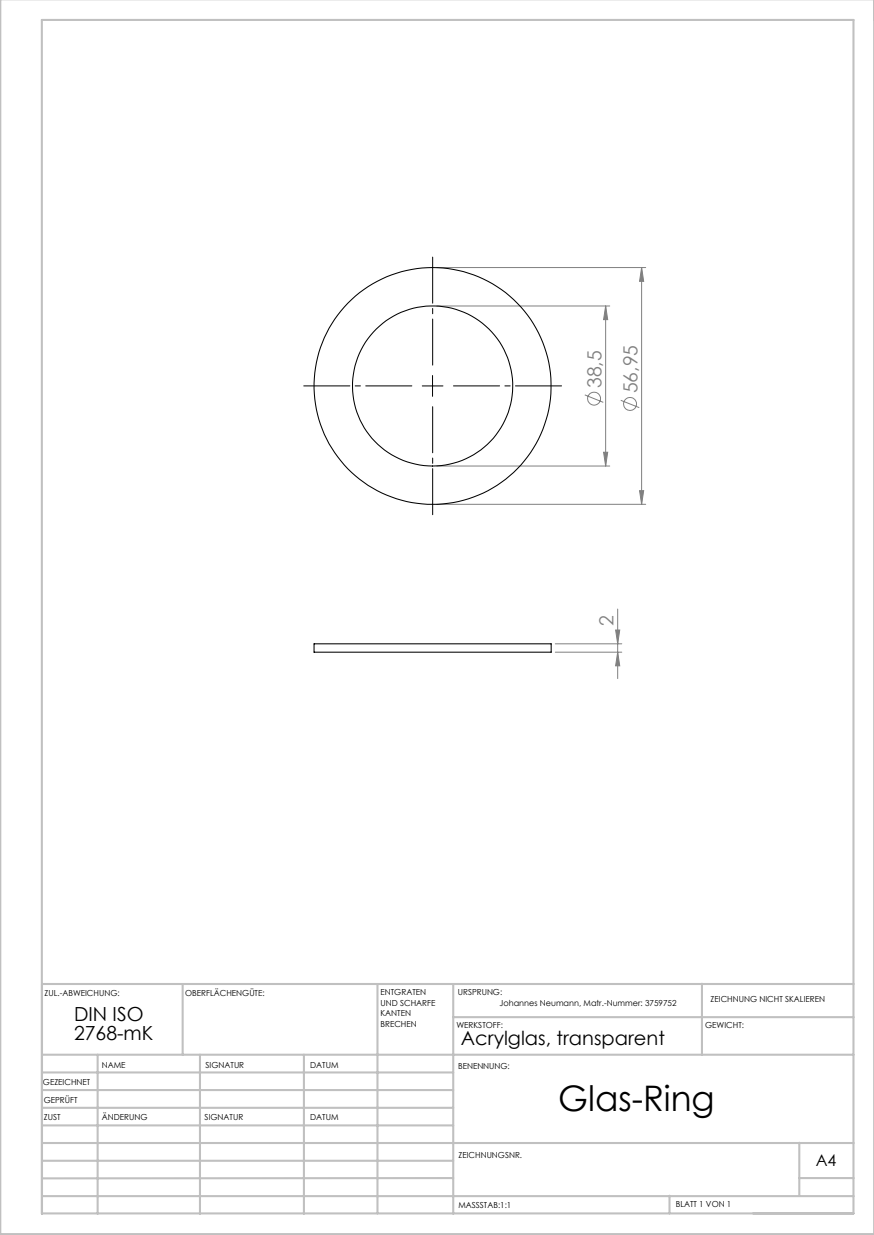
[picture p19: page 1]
MASSSTAB:1:1; BLATT 1 VON 1

ZUL.-ABWEICHUNG: DIN ISO 2768-mK | OBERFLÄCHENGÜTE: | ENTGRATEN UND SCHARFE KANTEN BRECHEN | URSPRUNG: Johannes Neumann, Matr.-Nummer: 3759752 | ZEICHNUNG NICHT SKALIEREN
NAME | SIGNATUR | DATUM | | BENENNUNG: Glas-Ring

WERKSTOFF: Acrylglas, transparent | GEWICHT:

GEZEICHNET
GEPRÜFT
ZUST | ÄNDERUNG | SIGNATUR | DATUM

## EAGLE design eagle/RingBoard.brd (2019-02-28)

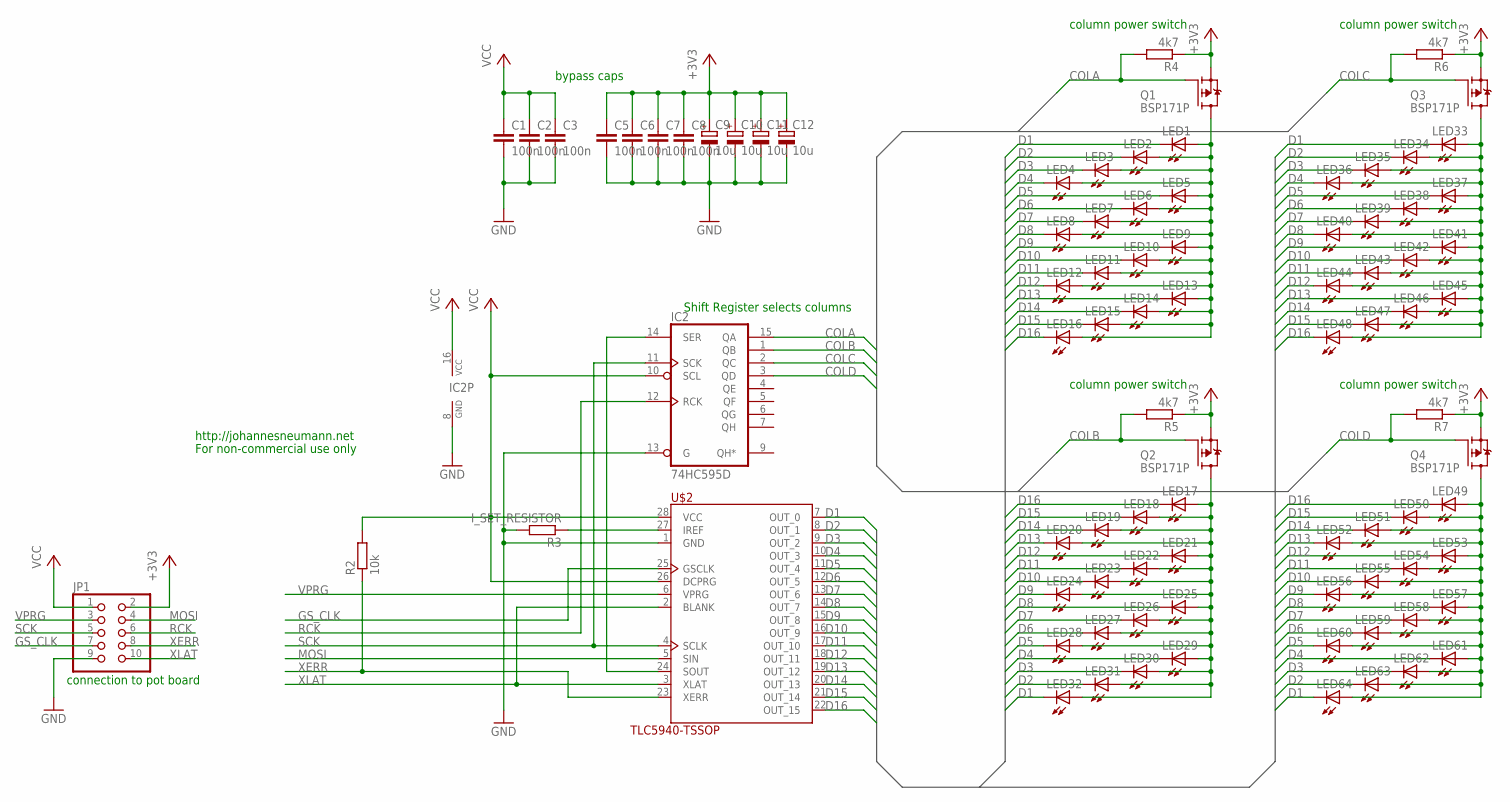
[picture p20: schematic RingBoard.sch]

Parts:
C1, C2, C3, C5, C6, C7, C8: 100n; C0603
C9, C10, C11, C12: 10u; 153CLV-0605
IC2: 74HC595D; SO16
JP1: PINHD-2X5_2.54-SMD; 2X05SMD
LED1, LED2, LED3, LED4, LED5, LED6, LED7, LED8, LED9, LED10, LED11, LED12, LED13, LED14, LED15, LED16, LED17, LED18, LED19, LED20, LED21, LED22, LED23, LED24, LED25, LED26, LED27, LED28, LED29, LED30, LED31, LED32, LED33, LED34, LED35, LED36, LED37, LED38, LED39, LED40, LED41, LED42, LED43, LED44, LED45, LED46, LED47, LED48, LED49, LED50, LED51, LED52, LED53, LED54, LED55, LED56, LED57, LED58, LED59, LED60, LED61, LED62, LED63, LED64: LEDCHIP-LED0805; CHIP-LED0805
Q1, Q2, Q3, Q4: BSP171P; SOT223
R2: 10k; R0603
R3: I_SET_RESISTOR; M1406
R4, R5, R6, R7: 4k7; R0603
U$2: TLC5940-TSSOP; HTSSOP-28

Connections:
+3V3: C5.1, C6.1, C7.1, C8.1, C9.+, C10.+, C11.+, C12.+, JP1.2, Q1.3 (S), Q2.3 (S), Q3.3 (S), Q4.3 (S), R4.1, R5.1, R6.1, R7.1
COLA: IC2.15 (QA), Q1.1 (G), R4.2
COLB: IC2.1 (QB), Q2.1 (G), R5.2
COLC: IC2.2 (QC), Q3.1 (G), R6.2
COLD: IC2.3 (QD), Q4.1 (G), R7.2
D1: LED1.C, LED32.C, LED33.C, LED64.C, U$2.7 (OUT_0)
D2: LED2.C, LED31.C, LED34.C, LED63.C, U$2.8 (OUT_1)
D3: LED3.C, LED30.C, LED35.C, LED62.C, U$2.9 (OUT_2)
D4: LED4.C, LED29.C, LED36.C, LED61.C, U$2.10 (OUT_3)
D5: LED5.C, LED28.C, LED37.C, LED60.C, U$2.11 (OUT_4)
D6: LED6.C, LED27.C, LED38.C, LED59.C, U$2.12 (OUT_5)
D7: LED7.C, LED26.C, LED39.C, LED58.C, U$2.13 (OUT_6)
D8: LED8.C, LED25.C, LED40.C, LED57.C, U$2.14 (OUT_7)
D9: LED9.C, LED24.C, LED41.C, LED56.C, U$2.15 (OUT_8)
D10: LED10.C, LED23.C, LED42.C, LED55.C, U$2.16 (OUT_9)
D11: LED11.C, LED22.C, LED43.C, LED54.C, U$2.17 (OUT_10)
D12: LED12.C, LED21.C, LED44.C, LED53.C, U$2.18 (OUT_11)
D13: LED13.C, LED20.C, LED45.C, LED52.C, U$2.19 (OUT_12)
D14: LED14.C, LED19.C, LED46.C, LED51.C, U$2.20 (OUT_13)
D15: LED15.C, LED18.C, LED47.C, LED50.C, U$2.21 (OUT_14)
D16: LED16.C, LED17.C, LED48.C, LED49.C, U$2.22 (OUT_15)
GND: C1.2, C2.2, C3.2, C5.2, C6.2, C7.2, C8.2, C9.-, C10.-, C11.-, C12.-, IC2.8 (GND), IC2.13 (G), JP1.9, R3.2, U$2.1 (GND)
GS_CLK: JP1.7, U$2.25 (GSCLK)
MOSI: JP1.4, U$2.5 (SIN)
unnamed: IC2.14 (SER), U$2.24 (SOUT)
unnamed: LED17.A, LED18.A, LED19.A, LED20.A, LED21.A, LED22.A, LED23.A, LED24.A, LED25.A, LED26.A, LED27.A, LED28.A, LED29.A, LED30.A, LED31.A, LED32.A, Q2.2 (D), Q2.4 (D)
unnamed: LED33.A, LED34.A, LED35.A, LED36.A, LED37.A, LED38.A, LED39.A, LED40.A, LED41.A, LED42.A, LED43.A, LED44.A, LED45.A, LED46.A, LED47.A, LED48.A, Q3.2 (D), Q3.4 (D)
unnamed: LED49.A, LED50.A, LED51.A, LED52.A, LED53.A, LED54.A, LED55.A, LED56.A, LED57.A, LED58.A, LED59.A, LED60.A, LED61.A, LED62.A, LED63.A, LED64.A, Q4.2 (D), Q4.4 (D)
unnamed: LED1.A, LED2.A, LED3.A, LED4.A, LED5.A, LED6.A, LED7.A, LED8.A, LED9.A, LED10.A, LED11.A, LED12.A, LED13.A, LED14.A, LED15.A, LED16.A, Q1.2 (D), Q1.4 (D)
unnamed: R3.1, U$2.27 (IREF)
RCK: IC2.12 (RCK), JP1.6
SCK: IC2.11 (SCK), JP1.5, U$2.4 (SCLK)
VCC: C1.1, C2.1, C3.1, IC2.10 (SCL), IC2.16 (VCC), JP1.1, R2.2, U$2.26 (DCPRG), U$2.28 (VCC)
VPRG: JP1.3, U$2.6 (VPRG)
XERR: JP1.8, R2.1, U$2.23 (XERR)
XLAT: JP1.10, U$2.2 (BLANK), U$2.3 (XLAT)

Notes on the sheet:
Shift Register selects columns
http://johannesneumann.net
For non-commercial use only
connection to pot board
column power switch
bypass caps

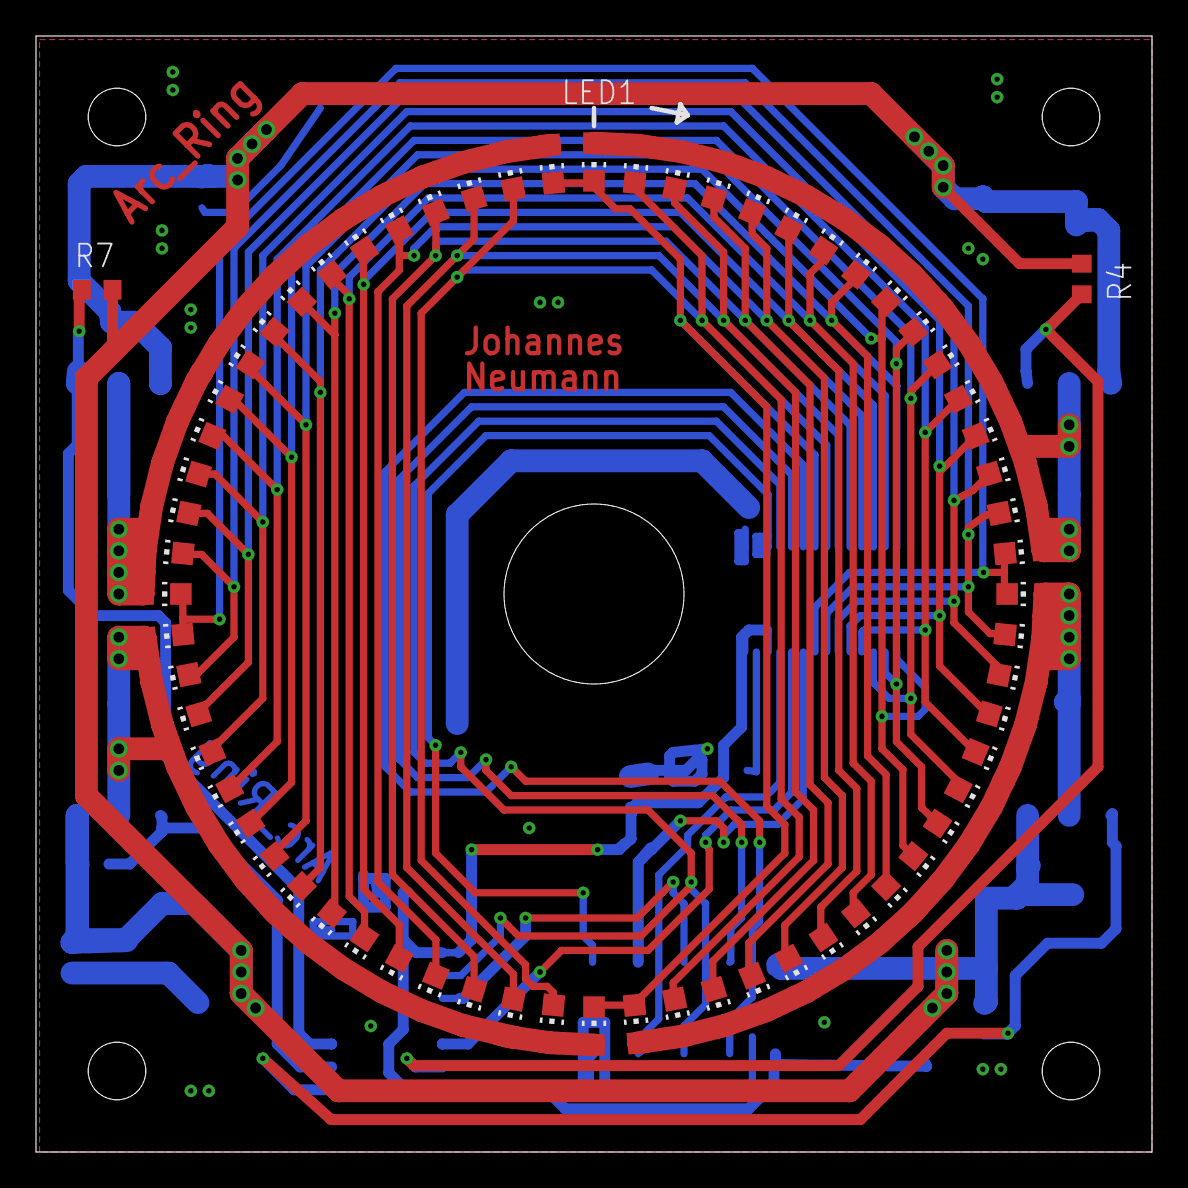
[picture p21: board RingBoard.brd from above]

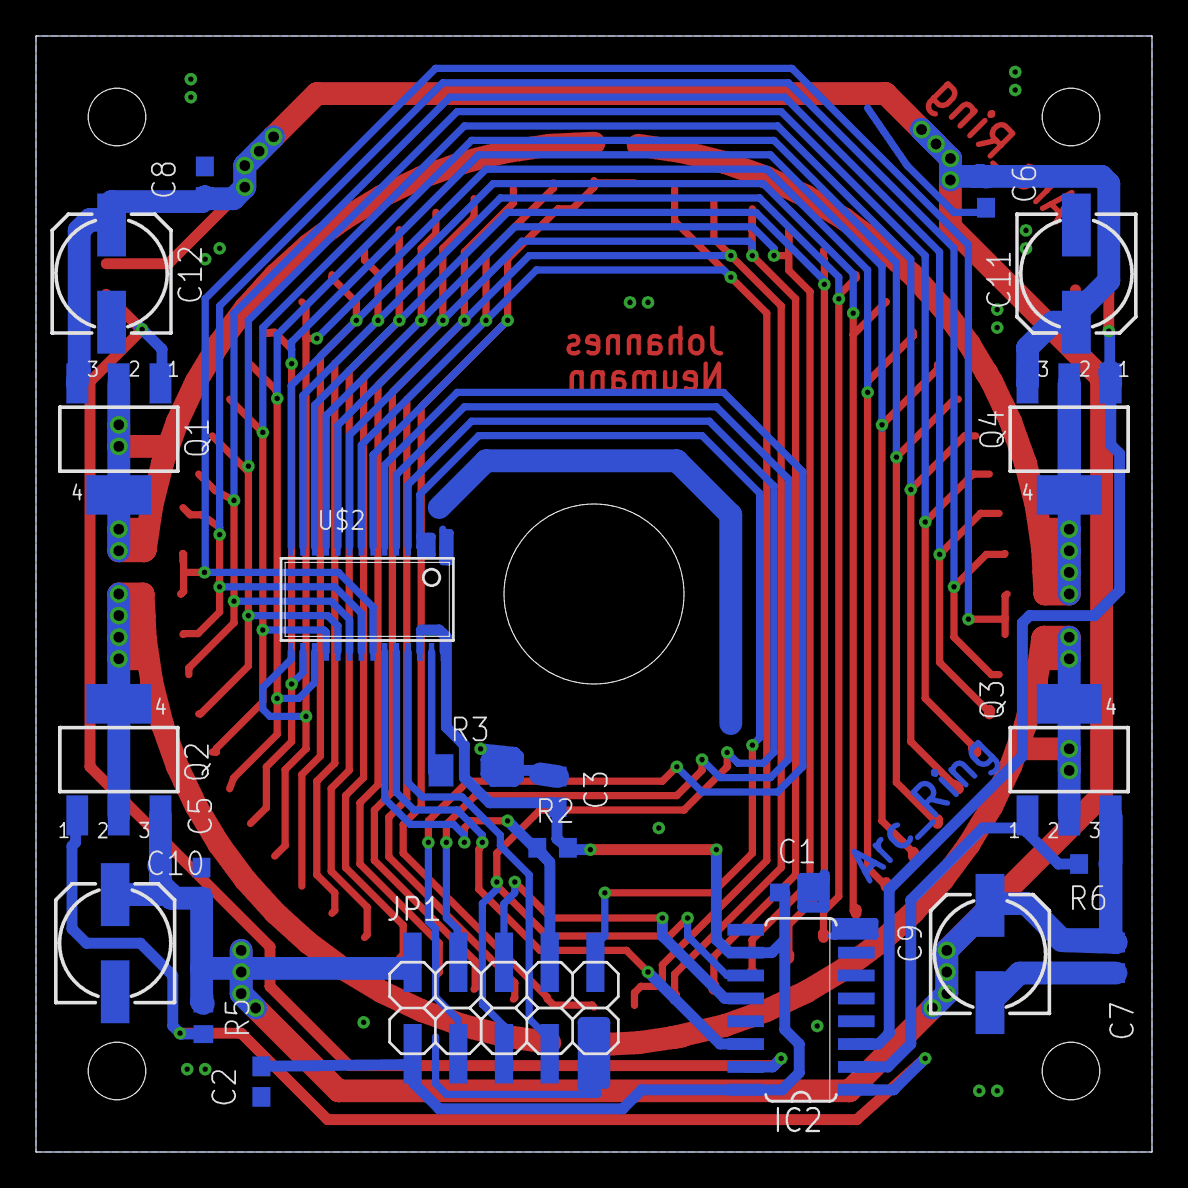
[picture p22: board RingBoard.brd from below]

Board: 2 copper layers, 62.0 x 62.0 mm, 88 parts (22 on the bottom side), 36 nets.

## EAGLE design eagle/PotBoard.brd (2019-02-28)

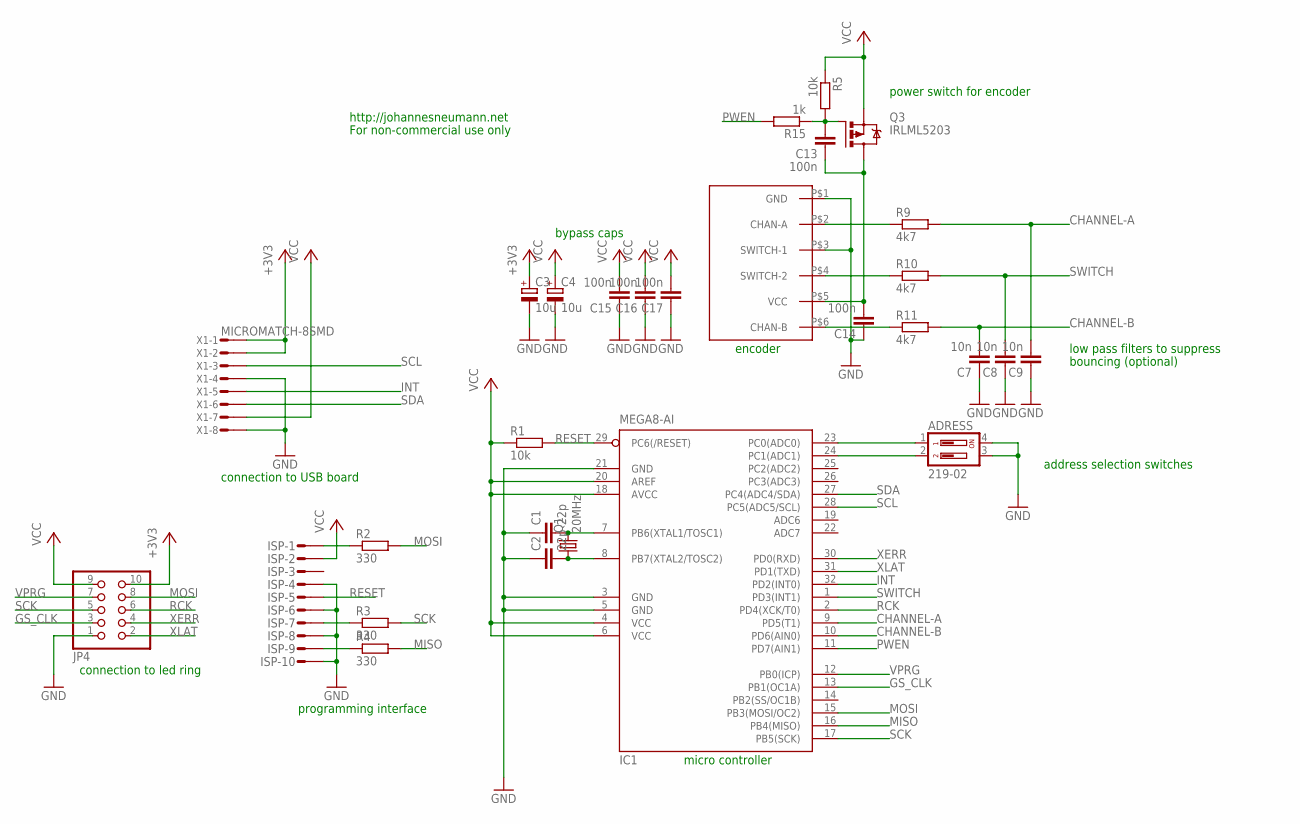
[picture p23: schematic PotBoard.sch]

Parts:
ADRESS: 219-02; CTS-219-02
C1, C2: 22p; C0603
C3, C4: 10u; 153CLV-0505
C7, C8, C9: 10n; C0603
C13, C14, C15, C16, C17: 100n; C0603
IC1: MEGA8-AI; TQFP32-08
ISP: MICROMATCH-10-SMD
JP4: PINHD-2X5_2.54-SMD; 2X05SMD
Q1: 20MHz; SM49
Q3: IRLML5203; MICRO3
R1, R5: 10k; R0603
R2, R3, R4: 330; R0603
R9, R10, R11: 4k7; R0603
R15: 1k; R0603
U$1: BOURNS_EM14; BOURNS_EM14_AXIAL
X1: MICROMATCH-8SMD; MICROMATCH-8-SMD

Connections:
+3V3: C3.+, JP4.10, X1.1, X1.2
CHANNEL-A: C9.2, IC1.9 (PD5(T1)), R9.2
CHANNEL-B: C7.2, IC1.10 (PD6(AIN0)), R11.2
GND: ADRESS.3, ADRESS.4, C1.1, C2.1, C3.-, C4.-, C7.1, C8.1, C9.1, C14.1, C15.1, C16.1, C17.1, IC1.3 (GND), IC1.5 (GND), IC1.21 (GND), ISP.P$4, ISP.P$6, ISP.P$8, ISP.P$10, JP4.1, U$1.P$1 (GND), U$1.P$3 (SWITCH-1), X1.4, X1.8
GS_CLK: IC1.13 (PB1(OC1A)), JP4.3
INT: IC1.32 (PD2(INT0)), X1.5
MISO: IC1.16 (PB4(MISO)), R4.2
MOSI: IC1.15 (PB3(MOSI/OC2)), JP4.8, R2.2
unnamed: C1.2, IC1.7 (PB6(XTAL1/TOSC1)), Q1.2
unnamed: C2.2, IC1.8 (PB7(XTAL2/TOSC2)), Q1.1
unnamed: ISP.P$1, R2.1
unnamed: ISP.P$7, R3.1
unnamed: ISP.P$9, R4.1
unnamed: ADRESS.1, IC1.23 (PC0(ADC0))
unnamed: ADRESS.2, IC1.24 (PC1(ADC1))
unnamed: R11.1, U$1.P$6 (CHAN-B)
unnamed: R10.1, U$1.P$4 (SWITCH-2)
unnamed: R9.1, U$1.P$2 (CHAN-A)
unnamed: C13.2, Q3.1 (G), R5.2, R15.1
unnamed: C13.1, C14.2, Q3.3 (D), U$1.P$5 (VCC)
PWEN: IC1.11 (PD7(AIN1)), R15.2
RCK: IC1.2 (PD4(XCK/T0)), JP4.6
RESET: IC1.29 (PC6(/RESET)), ISP.P$5, R1.2
SCK: IC1.17 (PB5(SCK)), JP4.5, R3.2
SCL: IC1.28 (PC5(ADC5/SCL)), X1.3
SDA: IC1.27 (PC4(ADC4/SDA)), X1.6
SWITCH: C8.2, IC1.1 (PD3(INT1)), R10.2
VCC: C4.+, C15.2, C16.2, C17.2, IC1.4 (VCC), IC1.6 (VCC), IC1.18 (AVCC), IC1.20 (AREF), ISP.P$2, JP4.9, Q3.2 (S), R1.1, R5.1, X1.7
VPRG: IC1.12 (PB0(ICP)), JP4.7
XERR: IC1.30 (PD0(RXD)), JP4.4
XLAT: IC1.31 (PD1(TXD)), JP4.2

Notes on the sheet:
http://johannesneumann.net
For non-commercial use only
power switch for encoder
encoder
low pass filters to suppress
bouncing (optional)
address selection switches
connection to led ring
programming interface
connection to USB board
bypass caps
micro controller

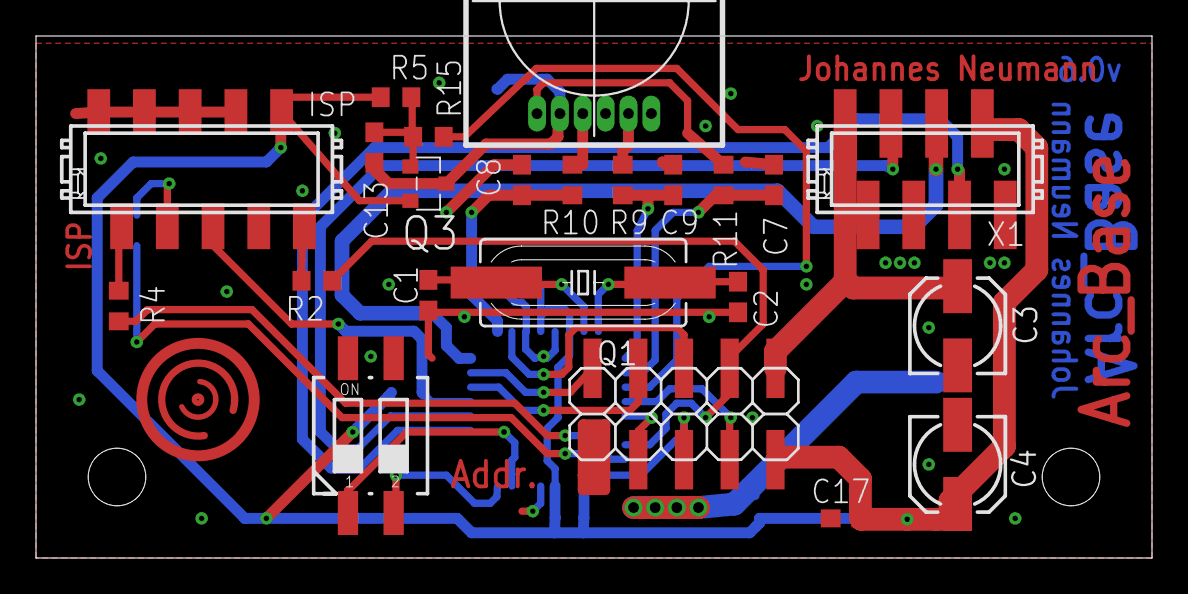
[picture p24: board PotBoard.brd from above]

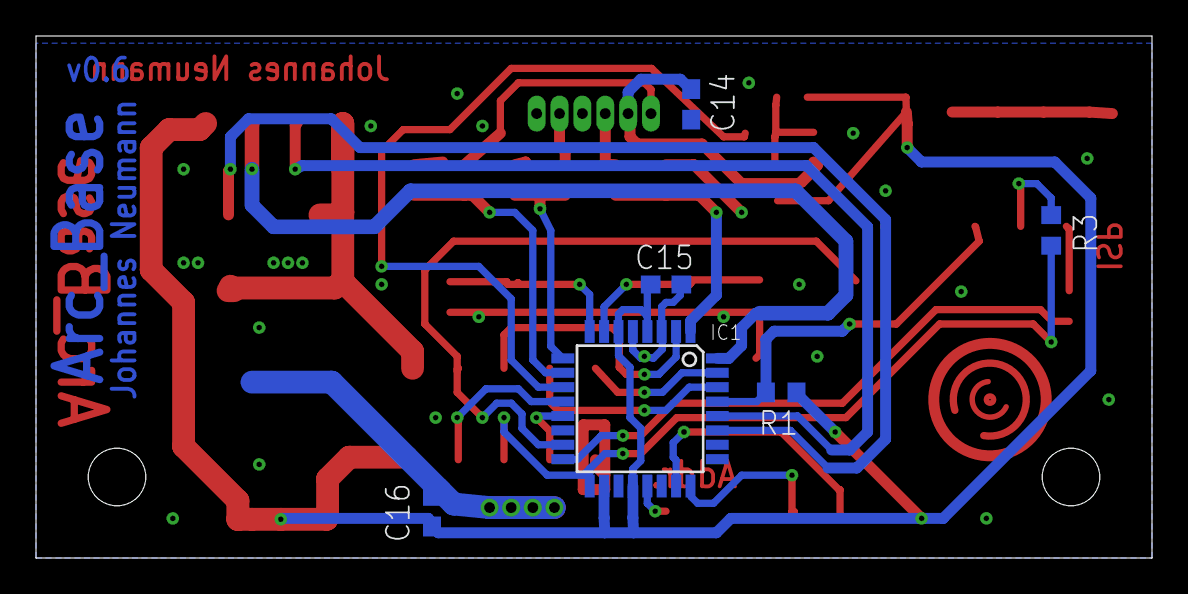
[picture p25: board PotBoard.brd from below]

Board: 2 copper layers, 62.0 x 29.0 mm, 29 parts (6 on the bottom side), 31 nets.

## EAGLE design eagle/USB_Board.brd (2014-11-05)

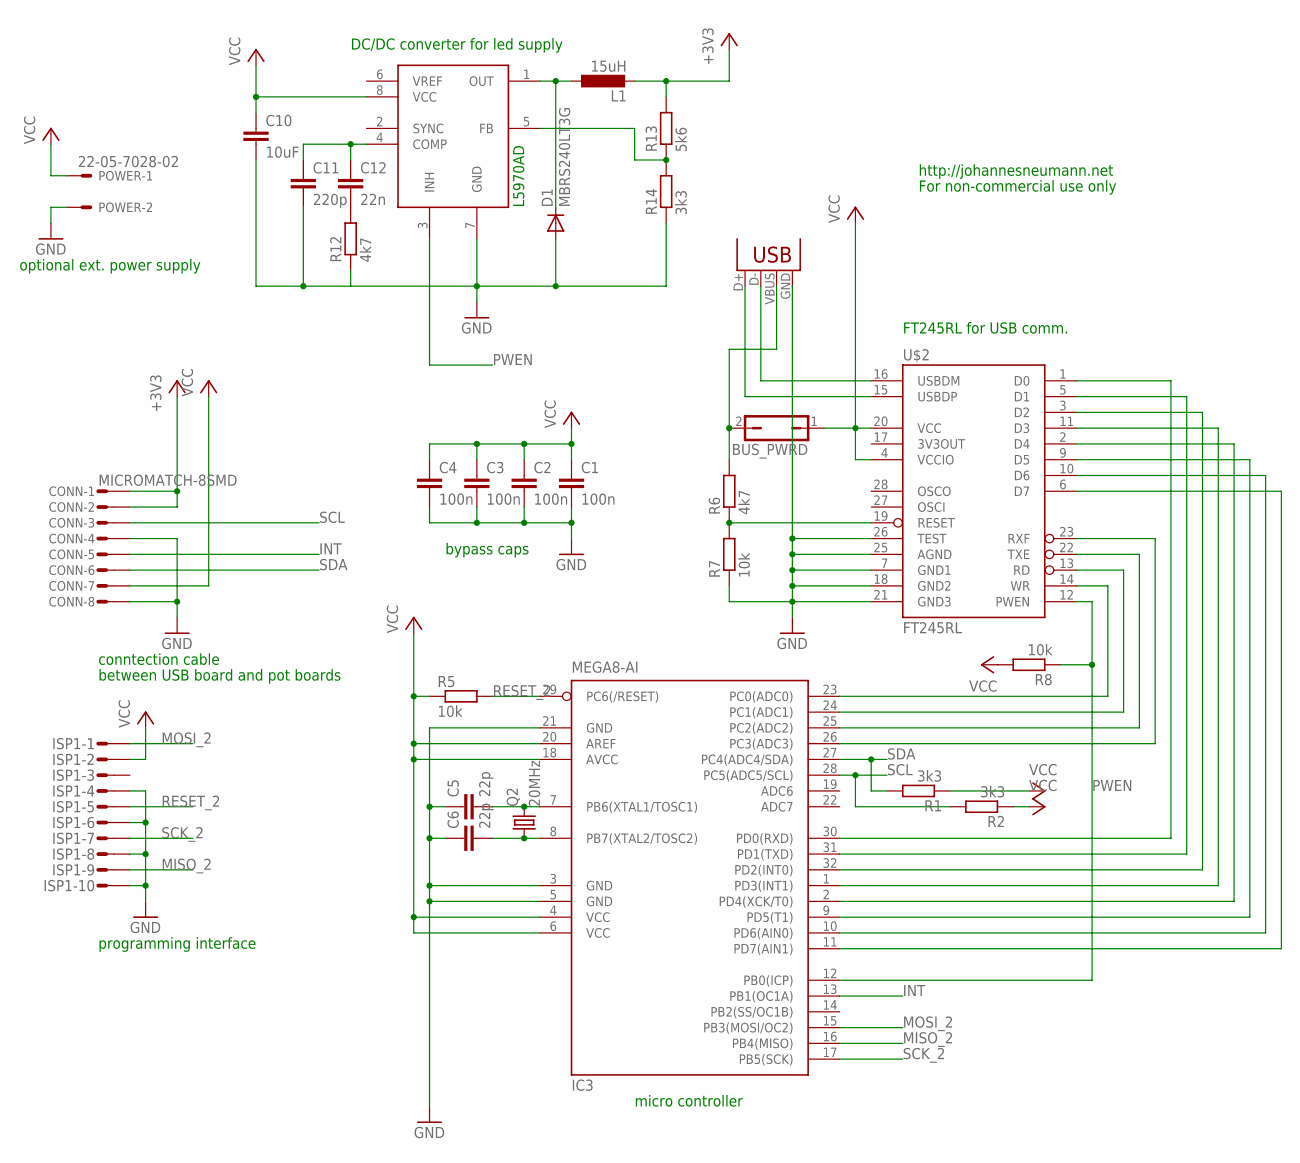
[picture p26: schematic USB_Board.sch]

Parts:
BUS_PWRD: JP1Q; JP1
C1, C2, C3, C4: 100n; C0603
C5, C6: 22p; C0603
C10: 10uF; C0805
C11: 220p; C0603
C12: 22n; C0603
CONN: MICROMATCH-8SMD; MICROMATCH-8-SMD
D1: MBRS240LT3G; DO41-10
IC3: MEGA8-AI; TQFP32-08
ISP1: MICROMATCH-10-SMD
L1: 15uH; PIS2816
POWER: 22-05-7028-02; 7395-02
Q2: 20MHz; SM49
R1, R2, R14: 3k3; R0603
R5, R7, R8: 10k; R0603
R6, R12: 4k7; R0603
R13: 5k6; R0603
U$2: FT245RL; SSOP28DB
U$3: L5970AD; SO8
X1: USBPTH; USB-B-PTH

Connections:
+3V3: CONN.1, CONN.2, L1.2, R13.2
GND: C1.2, C2.2, C3.2, C4.2, C5.1, C6.1, C10.2, C11.2, CONN.4, CONN.8, D1.A, IC3.3 (GND), IC3.5 (GND), IC3.21 (GND), ISP1.P$4, ISP1.P$6, ISP1.P$8, ISP1.P$10, POWER.2, R7.1, R12.1, R14.1, U$2.7 (GND1), U$2.18 (GND2), U$2.21 (GND3), U$2.25 (AGND), U$2.26 (TEST), U$3.7 (GND), X1.GND
INT: CONN.5, IC3.13 (PB1(OC1A))
MISO_2: IC3.16 (PB4(MISO)), ISP1.P$9
MOSI_2: IC3.15 (PB3(MOSI/OC2)), ISP1.P$1
unnamed: C5.2, IC3.7 (PB6(XTAL1/TOSC1)), Q2.2
unnamed: C6.2, IC3.8 (PB7(XTAL2/TOSC2)), Q2.1
unnamed: U$2.16 (USBDM), X1.D-
unnamed: IC3.30 (PD0(RXD)), U$2.1 (D0)
unnamed: IC3.31 (PD1(TXD)), U$2.5 (D1)
unnamed: IC3.32 (PD2(INT0)), U$2.3 (D2)
unnamed: IC3.1 (PD3(INT1)), U$2.11 (D3)
unnamed: IC3.2 (PD4(XCK/T0)), U$2.2 (D4)
unnamed: IC3.9 (PD5(T1)), U$2.9 (D5)
unnamed: IC3.10 (PD6(AIN0)), U$2.10 (D6)
unnamed: IC3.11 (PD7(AIN1)), U$2.6 (D7)
unnamed: IC3.26 (PC3(ADC3)), U$2.23 (RXF)
unnamed: IC3.25 (PC2(ADC2)), U$2.22 (TXE)
unnamed: IC3.24 (PC1(ADC1)), U$2.13 (RD)
unnamed: IC3.23 (PC0(ADC0)), U$2.14 (WR)
unnamed: D1.C, L1.1, U$3.1 (OUT)
unnamed: BUS_PWRD.2, R6.2, X1.VBUS
unnamed: R13.1, R14.2, U$3.5 (FB)
unnamed: C12.2, R12.2
unnamed: C11.1, C12.1, U$3.4 (COMP)
PWEN: IC3.12 (PB0(ICP)), R8.1, U$2.12 (PWEN), U$3.3 (INH)
PWR_ON: R6.1, R7.2, U$2.19 (RESET)
RESET_2: IC3.29 (PC6(/RESET)), ISP1.P$5, R5.2
SCK_2: IC3.17 (PB5(SCK)), ISP1.P$7
SCL: CONN.3, IC3.28 (PC5(ADC5/SCL)), R2.2
SDA: CONN.6, IC3.27 (PC4(ADC4/SDA)), R1.2
USB: U$2.15 (USBDP), X1.D+
VCC: BUS_PWRD.1, C1.1, C2.1, C3.1, C4.1, C10.1, CONN.7, IC3.4 (VCC), IC3.6 (VCC), IC3.18 (AVCC), IC3.20 (AREF), ISP1.P$2, POWER.1, R1.1, R2.1, R5.1, R8.2, U$2.4 (VCCIO), U$2.20 (VCC), U$3.8 (VCC)

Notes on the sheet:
programming interface
conntection cable
between USB board and pot boards
optional ext. power supply
DC/DC converter for led supply
FT245RL for USB comm.
micro controller
bypass caps
http://johannesneumann.net
For non-commercial use only
L5970AD

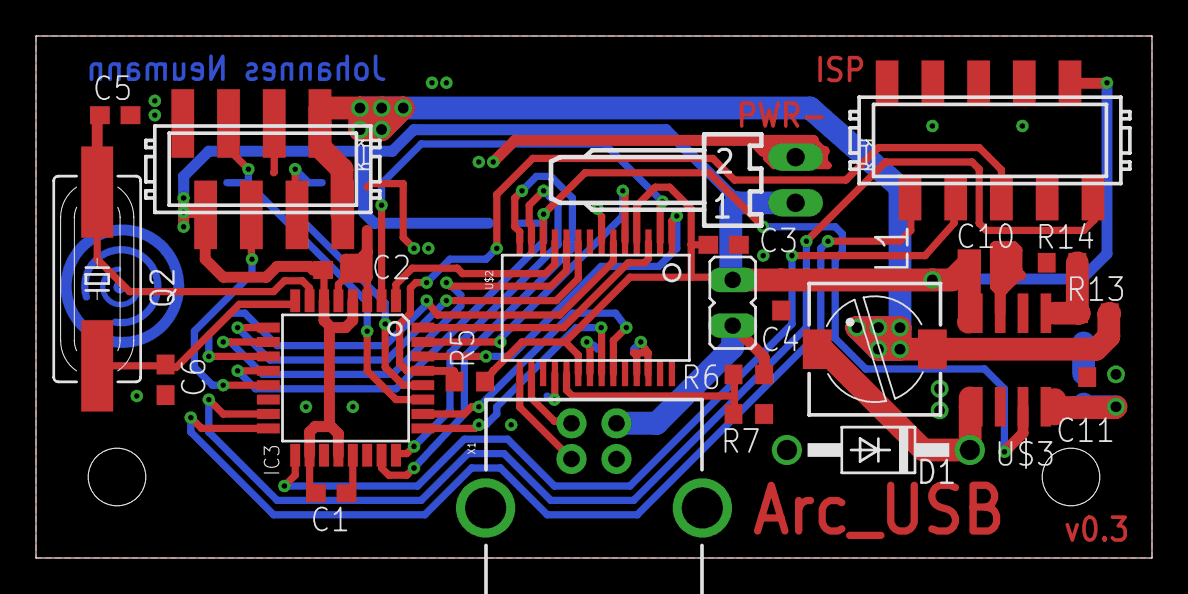
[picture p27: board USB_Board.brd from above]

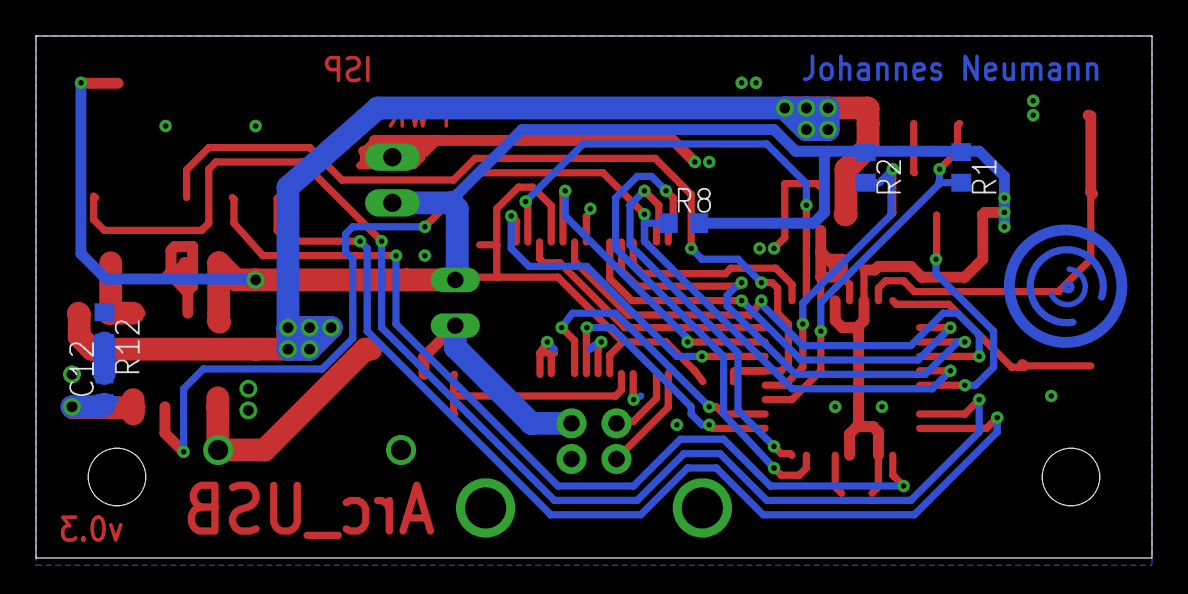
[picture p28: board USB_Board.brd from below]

Board: 2 copper layers, 62.0 x 29.0 mm, 29 parts (5 on the bottom side), 33 nets.

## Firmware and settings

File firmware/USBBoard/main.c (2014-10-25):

/*	 This file contains source code for the firmware of a monome arc 
 *   clone.
 * 
 *   Copyright (C) 2013  Johannes Neumann; mail@johannesneumann.net
 *
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
 *   You should have received a copy of the GNU General Public License
 *   along with this program.  If not, see <http://www.gnu.org/licenses/>.
 */  
 
// This file contains the main function

#include <inttypes.h>
#include <avr/io.h>
#include <stdlib.h>
#include <avr/interrupt.h>
#include <util/delay.h>
#include <string.h>
#include <math.h>

// defines for the I2C interface
#define I2C_MAX_MESSAGE_OUT_LENGTH 34
#define I2C_MAX_MESSAGE_IN_LENGTH 4

#define I2C_BUFFER_OUT_LENGTH 4
#define I2C_BUFFER_IN_LENGTH 4

#define I2C_PORT PINC
#define I2C_SDA_PIN PC4
#define I2C_SCL_PIN PC5

#include "../protocol.h"
#include "i2c_m.c"
#include "ftdi.c"
#include "led_buffer.c"
#include "config.c"
#include "startup_animation.h"

uint8_t button_down[NUM_ENCS];
int8_t encoder_turns[NUM_ENCS];

uint8_t current_slave_input;
uint8_t current_slave_output;

//flags
uint8_t must_activate_power;
uint8_t must_deactivate_power;


void processNewMessages( void ) 
{
		
	while (i2c_hasIncomingMessages()) {
		
		volatile struct i2c_message_in* m;
		m = i2c_getInputBufferBack();
		
		if (((m->data[0] & 0xF0) == PROT_BUTTON) 
			&& (m->length == PROT_BUTTON_LENGTH)) {
				
			uint8_t from = (m->data[1] & 0b01111111) - 1;
				
			if (m->data[1] & 0b10000000) 
			{
				while (!FTDI_canTakeNewByte())
					FTDI_trySendCommandsToHost();
				FTDI_addOutputBufferFront(COMM_O_ENCODER_DOWN);
				
				while (!FTDI_canTakeNewByte())
					FTDI_trySendCommandsToHost();
				FTDI_addOutputBufferFront(from);
			} 
			else 
			{
				while (!FTDI_canTakeNewByte())
					FTDI_trySendCommandsToHost();
				FTDI_addOutputBufferFront(COMM_O_ENCODER_UP);
				
				while (!FTDI_canTakeNewByte())
					FTDI_trySendCommandsToHost();
				FTDI_addOutputBufferFront(from);
			}
		} 
		else if (((m->data[0] & 0xF0) == PROT_ENCODER_TURNED) 
			&& (m->length == PROT_ENCODER_TURNED_LENGTH)) 
		{
				
			uint8_t from = (m->data[1] & 0b01111111) - 1;
				
			while (!FTDI_canTakeNewByte())
				FTDI_trySendCommandsToHost();
			FTDI_addOutputBufferFront(COMM_O_ENCODER);
			
			while (!FTDI_canTakeNewByte())
				FTDI_trySendCommandsToHost();
			FTDI_addOutputBufferFront(from);
			
			while (!FTDI_canTakeNewByte())
				FTDI_trySendCommandsToHost();
			FTDI_addOutputBufferFront(m->data[2]);
		} 
		
		
		i2c_removeInputBufferBack();
	}
}

int main (void) 
{			
	_delay_ms(500);

	// Init Hardware...
	POWER_PIN_INIT;
	// enable pin change interrupt for PWREN pin
	PCICR |= (1 << PCIE0);     // set PCIE0 to enable PCMSK0
    PCMSK0 |= (1 << PCINT0);   // set PCINT0 to trigger an interrupt
	
	// enable timer
	TCCR2B |= (1<<CS22) | (1<<CS21);
	TIMSK2 |= (1<<TOIE2);
	
	INT_PULLUP;
	
	// Init variables ...
	current_slave_input = 0;
	current_slave_output = 0;
	
	// init software modules
	i2c_init();
	BUFFER_init();
	FTDI_init();
	
	// init flags
	must_activate_power = 1;
	must_deactivate_power = 0;

	// enable interrupts
	sei();

	while(1)
	{	
		FTDI_trySendCommandsToHost();
		processNewMessages();
		i2c_trySendMessages();
		
		// if INT is low, then a slave wants to send data
		if (!INT_IS_HIGH) 
		{
			// Try to get message from a slave, if message is sent, then try next slave
			// until the INT line goes high
			if (i2c_tryReceiveMessageFrom(current_slave_input + 1) >= 0) 
			{
				current_slave_input++;
				if (current_slave_input >= NUM_ENCS)
					current_slave_input = 0;
			}	
		}
		
		// try send wake-up command if neccessary
		while ((must_activate_power > 0) && i2c_canTakeNewOutgoingMessage()) 
		{
			struct i2c_message_out m;
			m.receiver = must_activate_power;
			m.length = PROT_POWER_MODE_LENGTH;
			m.data[0] = PROT_POWER_MODE | 0b00000001;
				
			i2c_addOutputBufferFront(m);
			must_activate_power--;
		}
		// try send sleep command if neccessary
		while ((must_deactivate_power > 0) && i2c_canTakeNewOutgoingMessage()) 
		{
			struct i2c_message_out m;
			m.receiver = must_deactivate_power;
			m.length = PROT_POWER_MODE_LENGTH;
			m.data[0] = PROT_POWER_MODE | 0b00000000;
			
			i2c_addOutputBufferFront(m);
			must_deactivate_power--;
		}
	}
	
	return 0;
}

// called every three ms
ISR(TIMER2_OVF_vect) {
	if (POWER_DISABLED)
		return;
		
	// run startup animation (only done once)
	runStartupAnimation();
	
	// try to update a slave with new display data
	if (i2c_canTakeNewOutgoingMessage()) 
	{
		struct i2c_message_out m;
		m.receiver = current_slave_output+1;
		m.length = PROT_SET_ALL_LEDS_LENGTH;
		m.data[0] = PROT_SET_ALL_LEDS;
		
		uint8_t t;
		for (t = 0; t < 32; t++) 
		{	
			m.data[t+1] = ((BUFFER_getLED(current_slave_output,2*t)<<4)&0xf0) | ((BUFFER_getLED(current_slave_output,2*t+1)) & 0x0f);
		}
		
		i2c_addOutputBufferFront(m);
		
		current_slave_output++;
		if (current_slave_output >= NUM_ENCS)
			current_slave_output = 0;
	}
}

// pin change interrupt for power pin
ISR(PCINT0_vect) 
{
	if (POWER_ENABLED) 
	{
		// in case the output buffer is full and can't take more 
		// messages, we would have to wait in this interrupt until
		// there is space, because this message MUST be sent to the 
		// slaves. 
		// To avoid this we just set a flag and do it in the main loop.
		// The flag will be decreased by one for every slave that has 
		// received a power mode message, thus all slaves will get a
		// message.
		must_activate_power = NUM_ENCS;
	}
	else
	{
		// see above
		must_deactivate_power = NUM_ENCS;
	}
}

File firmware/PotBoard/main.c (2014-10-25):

/*	 This file contains source code for the firmware of a monome arc 
 *   clone.
 * 
 *   Copyright (C) 2013  Johannes Neumann; mail@johannesneumann.net
 *
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
 *   You should have received a copy of the GNU General Public License
 *   along with this program.  If not, see <http://www.gnu.org/licenses/>.
 */  
 
// This file contains the main function

#include <inttypes.h>
#include <avr/io.h>
#include <stdlib.h>
#include <avr/interrupt.h>
#include <util/delay.h>
#include <string.h>
#include <math.h>

#include "leds.h"
#include "hardware.h"
#include "encoder.h"


// defines for the I2C interface
#define I2C_MAX_MESSAGE_OUT_LENGTH 4
#define I2C_MAX_MESSAGE_IN_LENGTH 34

#define I2C_BUFFER_OUT_LENGTH 6
#define I2C_BUFFER_IN_LENGTH 4

#define I2C_PORT PINC
#define I2C_SDA_PIN PC4
#define I2C_SCL_PIN PC5

#include "i2c_s.c"
#include "..\protocol.h"
#include "power.h"

int is_in_bounds(int16_t a, int16_t b, int16_t test) 
{
	if (a <= b) 
	{
		if ((test >= a) && (test <= b)) 
		{
			return 1;
		}
		else 
		{
			return 0; 
		}
	} else if (b < a) 
	{
		if ((test >= b) && (test <= a)) 
		{
			return 1;
		}
		else 
		{
			return 0; 
		}
	}
	return 0;		
}

void processNewMessages( void ) 
{
		
	while (i2c_hasIncomingMessages()) 
	{
		
		volatile struct i2c_message_in* m;
		m = i2c_getInputBufferBack();
		
		// clear command
		if (((m->data[0] & 0xF0) == PROT_CLEAR) 
			&& (m->length == PROT_CLEAR_LENGTH)) 
		{
			power_on();	
			uint8_t i;
			for (i = 0; i < 64; i++) 
			{
				setLED(i, 0);
			}
		} 
		// set single led command
		else if (((m->data[0] & 0xF0) == PROT_SET_SIGNLE_LED) 
			&& (m->length == PROT_SET_SIGNLE_LED_LENGTH)) 
		{
			power_on();	
			uint8_t led = ((m->data[0] & 0b00000011)<<4) | ((m->data[1]>>4) & 0x0f);
			uint8_t intensity = m->data[1] & 0x0f;
			setLED(led, intensity);
		}
		// set all leds command
		else if (((m->data[0] & 0xF0) == PROT_SET_ALL_LEDS) 
			&& (m->length == PROT_SET_ALL_LEDS_LENGTH)) 
		{
			power_on();
			uint8_t i;	
			for (i = 0; i < 32; i++) 
			{
				uint8_t intensitya = (m->data[i+1] & 0xf0) >> 4;
				uint8_t intensityb = m->data[i+1] & 0x0f;
				setLED(2*i, intensitya);
				setLED(2*i+1, intensityb);
			}
		}
		// power mode command
		else if (((m->data[0] & 0xF0) == PROT_POWER_MODE) 
			&& (m->length == PROT_POWER_MODE_LENGTH)) 
		{
			if (m->data[0] & 0b00000001) 
			{
				power_on();
			}
			else 
			{
				power_off();
			}
		}
		
		i2c_removeInputBufferBack();
	}
}

int main (void) 
{	
	ADDR_SW_PULLUPS;	
	_delay_ms(200);
	i2c_init(ADRR);
	
	powerInit();
	EncoderInit();
	LEDs_Init();
	
	sei();

	// main loop to do not-so-time-critical things
	while(1)
	{
		// check for changes on the encoder
		checkEncoder();	
		
		// process new messages from the USB board
		processNewMessages();
		
		// prepare new messages if necessary
		
		// first message: button changed?
		// check, if buffer can take new message
		if (i2c_canTakeNewOutgoingMessage()) 
		{
			// New button event
			if (newButtonEvent()) 
			{
				struct i2c_message_out m;
				m.length = PROT_BUTTON_LENGTH;
				m.data[0] = PROT_BUTTON;
				m.data[1] = i2c_getAdress()&0b01111111;
				
				if (getButtonState() == 1) 
					m.data[1] |= 0b10000000;
					
				// if message is stored in output buffer ...
				if (i2c_addOutputBufferFront(m)) {
					// ... mark this event as "sent".
					buttonEventSent();
				}
			}
		}
		
		// second message: encoder turned?
		// check once more, in case the buffer is full now
		if (i2c_canTakeNewOutgoingMessage()) 
		{
			// New encoder event
			int16_t turns = getTurns();
			
			if (turns != 0) 
			{
				struct i2c_message_out m;
				m.length = PROT_ENCODER_TURNED_LENGTH;
				m.data[0] = PROT_ENCODER_TURNED;
				m.data[1] = i2c_getAdress()&0b01111111;
				m.data[2] = (int8_t) turns;
					
				// if message is stored in output buffer ...
				if (i2c_addOutputBufferFront(m)) 
				{
					// ... mark this event as "sent".
					resetTurns();
				}
			}
		}
		
		// Try to start sending the previously prepared messages
		// messages a resent asynchronously, so this will only initiate 
		// sending something if necessary
		i2c_trySendMessages();
		
		
		// if the USB board told us to go to sleep, we should try to
		// sleep now
		//try_go_to_sleep();
	}
	
	return 0;
}

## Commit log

2014-11-05 Removed a stupid error from the pcbs and included an instructions file. Switched the firmware to use just two switches instead of four. No one's gonna build an arc16 anyway.
    [BOM.xlsx, PotBoard.brd, PotBoard.sch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]
2014-11-07 BOM fix
    [BOM.xlsx]
2018-11-28 Added FPD designer file, CSV BOMs for each board
    [BOM.csv, PotBoard.brd, PotBoard.csv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]
2018-11-28 Changed device ID to match original monome IDs
2019-02-27 Layer visibility change
    [RingBoard.brd]
2019-02-28 Updated BOM and documentation
    * Moved the assembly instructions to README.md
    * Added more detail and cross-platform instructions to many steps
    * Added section on physical assembly and case construction
    * Added design files detailing layout and suggested wooden case construction
    [BOM.csv, BOM.xlsx]

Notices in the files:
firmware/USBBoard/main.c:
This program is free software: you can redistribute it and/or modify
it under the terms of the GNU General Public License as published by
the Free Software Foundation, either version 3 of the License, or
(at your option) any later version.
